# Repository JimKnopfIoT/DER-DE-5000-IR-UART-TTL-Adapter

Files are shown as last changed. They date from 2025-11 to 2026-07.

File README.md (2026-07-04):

# DER EE DE-5000 IR-UART TTL-Adapter
3D printable IR-UART TTL-Adapter to connect a DER EE DE-5000 LCR Meter to a PC. Created with Rhino 8.

I stumbled across a thread on the eevblog forum about a piece of software to connect the DER EE DE-5000 using a self-made infrared-to-UART TTL bridge.
There was a 3D-printable enclosure. Since I own a DER EE DE-5000 LCR Meter, I redesigned the enclosure a bit to fit the contour of the device.

The enclosure consists of two parts that clamp together. When inserting the adapter, press a bit harder until it snaps.
Inside is a CP2102 UART adapter, an L-53P3C IR phototransistor (long leg connected to GND, short leg connected to RX) and a 4.7k Ohm resistor.
The resistor can have any value between 1k and 10k. I chose the 4.7k one because I have plenty of them.
I used some Kapton tape under the resistor.

The software can be found on the internet. It should also work with TestController (a well-known Java app).
I use 19200 baud 8N1, and on Windows I disabled power saving for this device in the Device Manager.

For printing the enclosure I used PETG and a 0.25 mm nozzle on my Prusa MK4S at 0.12 mm layer height.

<p align="center">
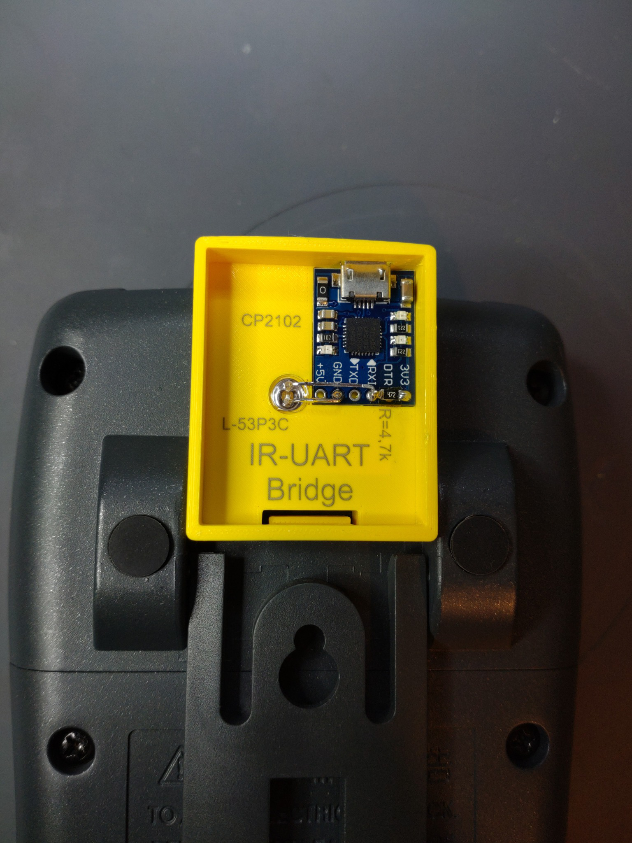
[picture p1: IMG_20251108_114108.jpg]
 
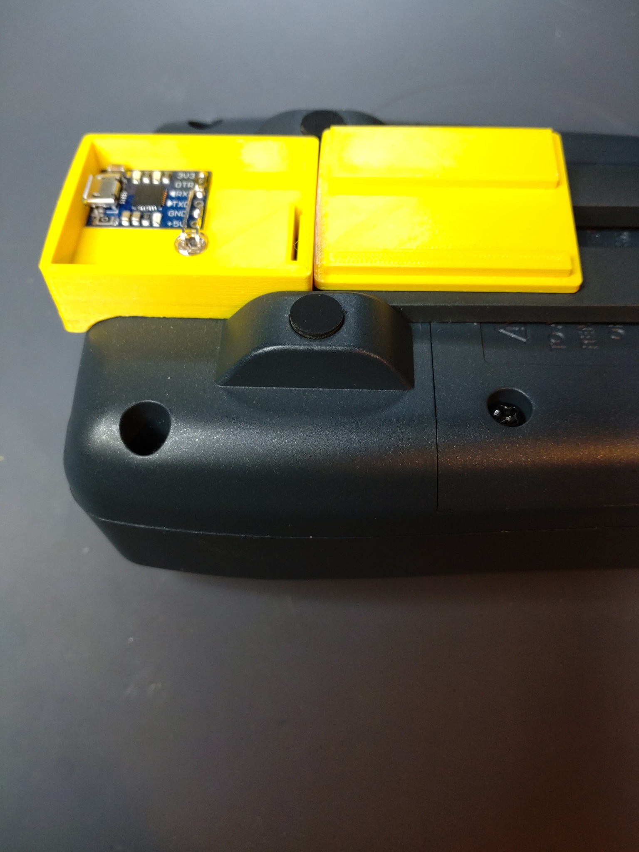
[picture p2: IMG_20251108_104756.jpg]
 
</p>

<p align="center">
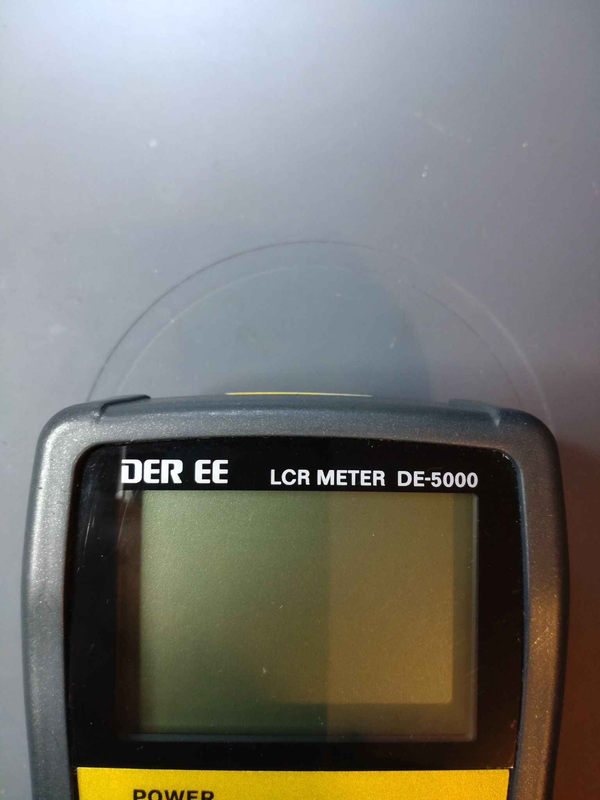
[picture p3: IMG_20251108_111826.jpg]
 
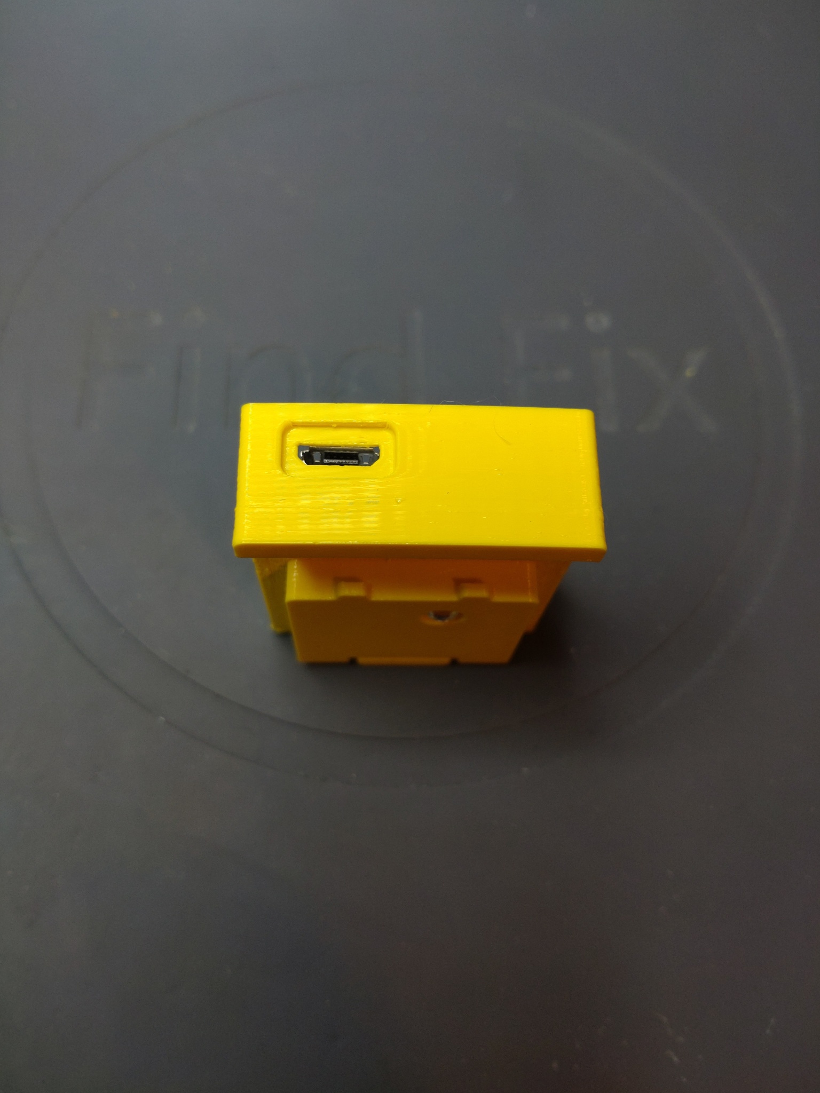
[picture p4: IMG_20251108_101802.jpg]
 
</p>

<p align="center">
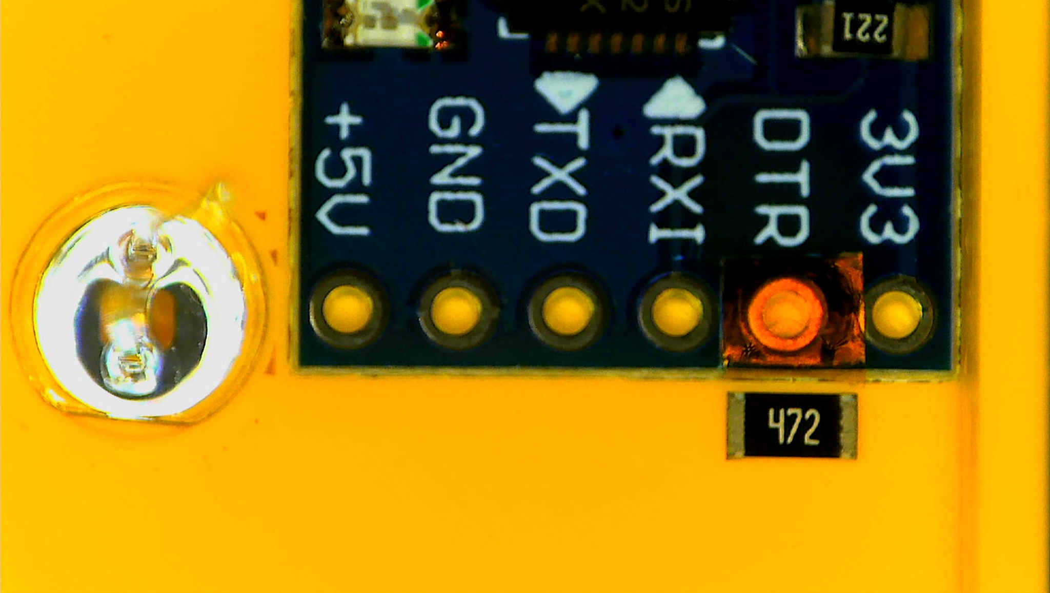
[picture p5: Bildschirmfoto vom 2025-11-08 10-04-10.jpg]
 
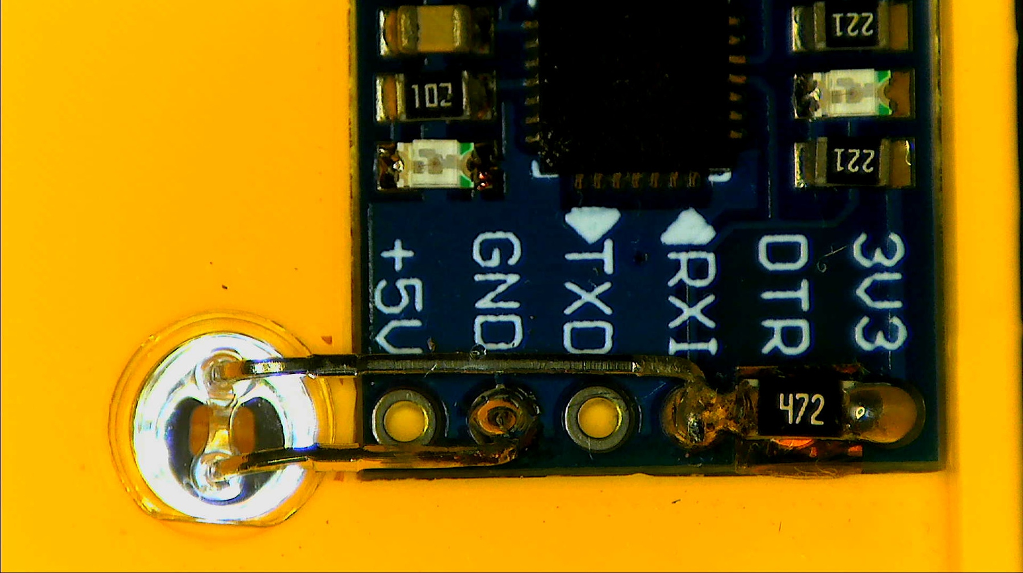
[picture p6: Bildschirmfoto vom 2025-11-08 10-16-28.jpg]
 
</p>

<p align="center">
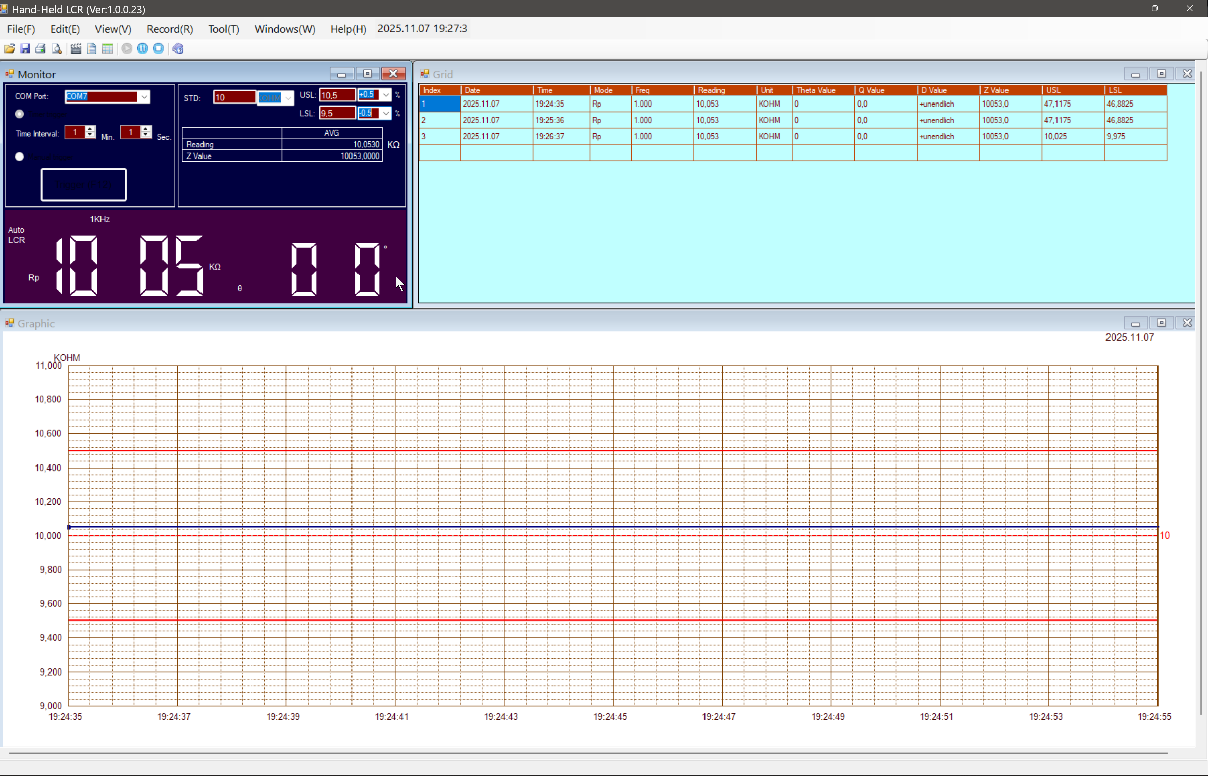
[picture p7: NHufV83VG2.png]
 
</p>

---

## **RN4871 Version (Bluetooth Low Energy)**

After the wired CP2102 version I built a wireless variant based on a Microchip **RN4871** BLE module. Instead of a USB cable, the meter data is now sent over Bluetooth Low Energy, so the meter stays completely galvanically isolated and cable-free from the PC.

<table align="center" border="0" cellspacing="8" cellpadding="0">
  <tr>
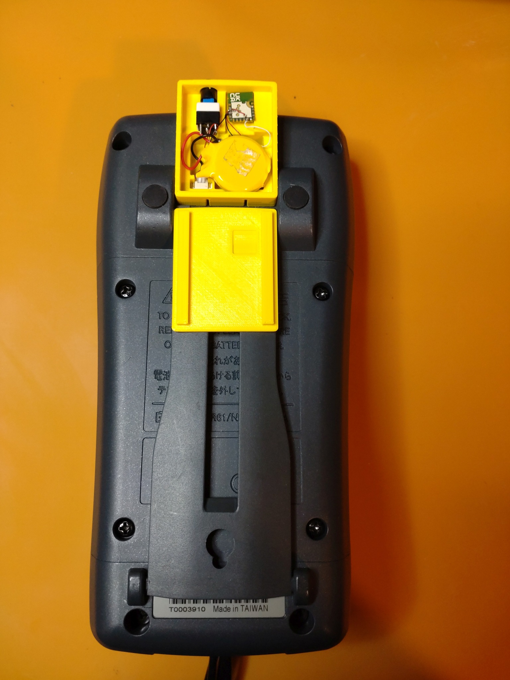
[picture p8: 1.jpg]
    <td></td>
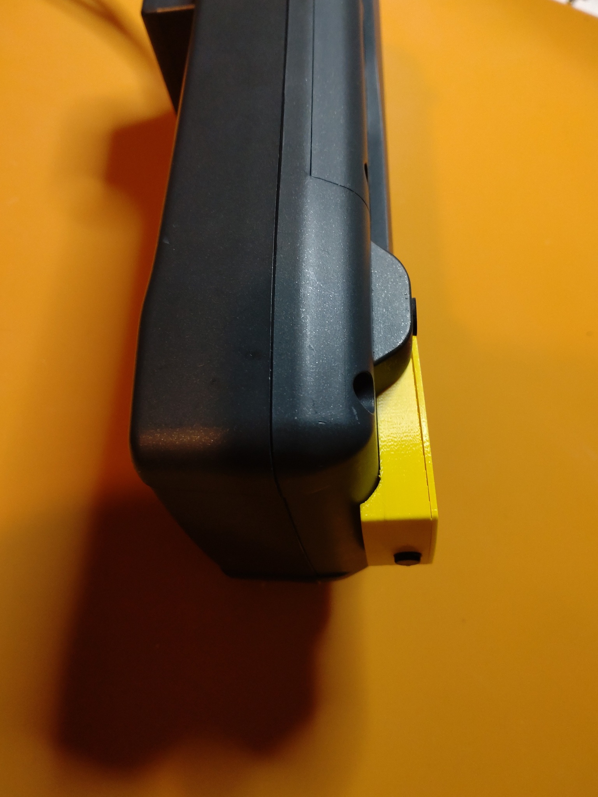
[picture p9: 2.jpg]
    <td></td>
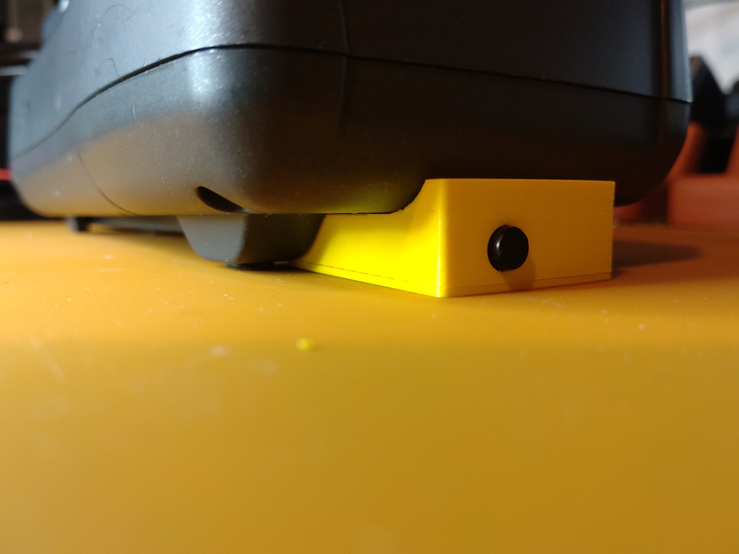
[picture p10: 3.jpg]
    <td></td>
  </tr>
  <tr>
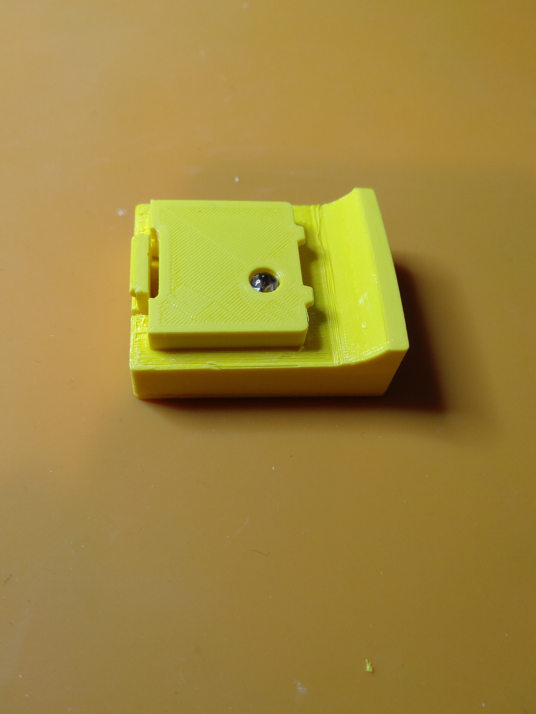
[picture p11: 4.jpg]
    <td></td>
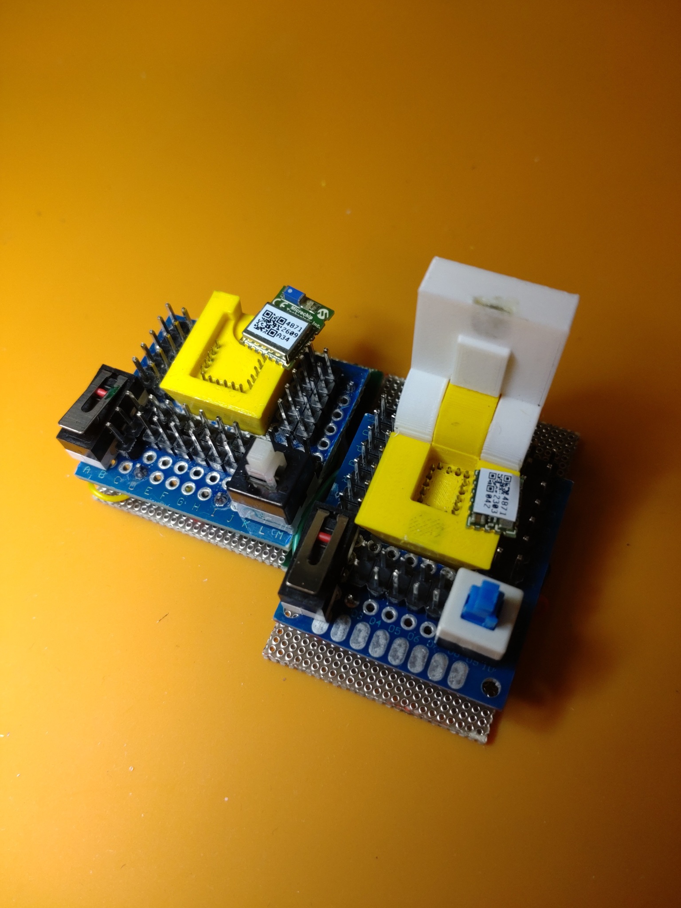
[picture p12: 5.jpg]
    <td></td>
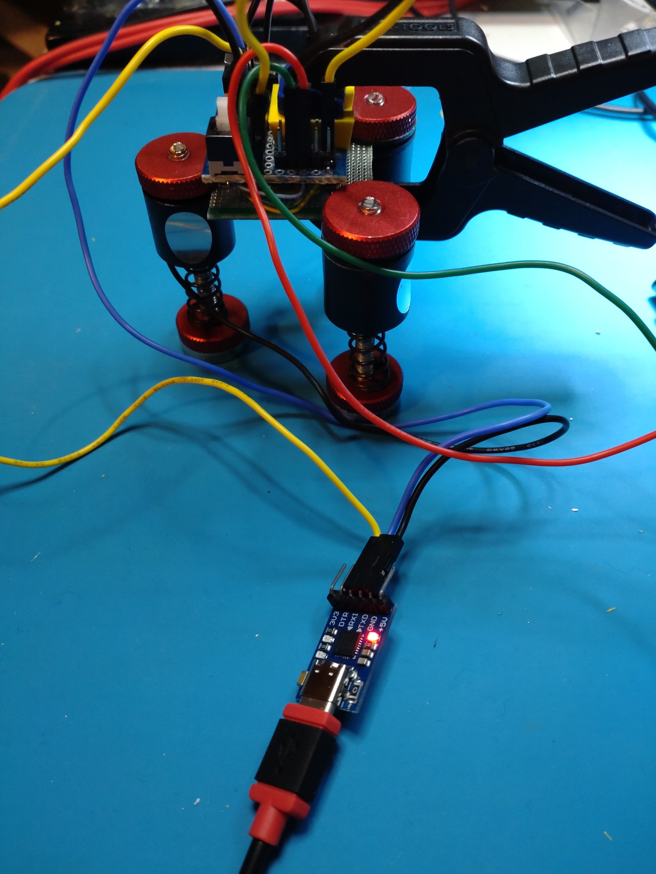
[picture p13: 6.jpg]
    <td></td>
  </tr>
  <tr>
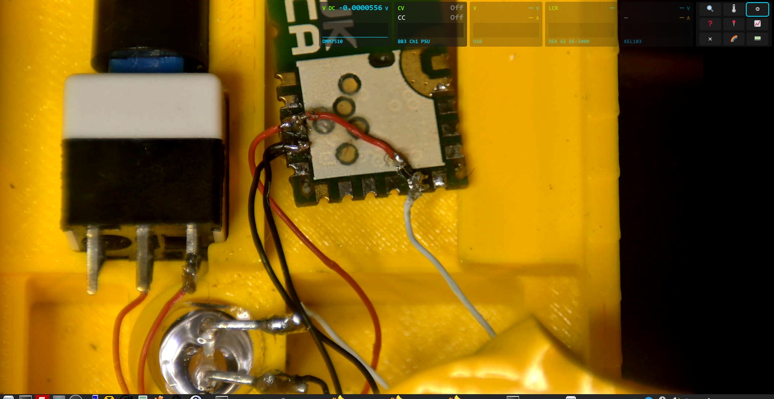
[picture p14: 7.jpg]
    <td></td>
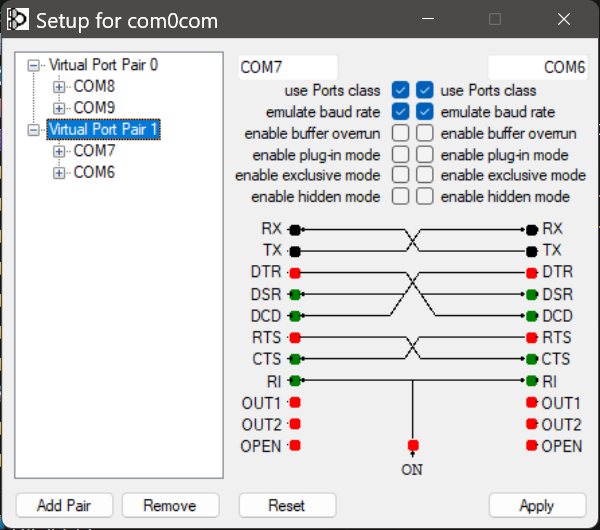
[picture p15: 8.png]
    <td></td>
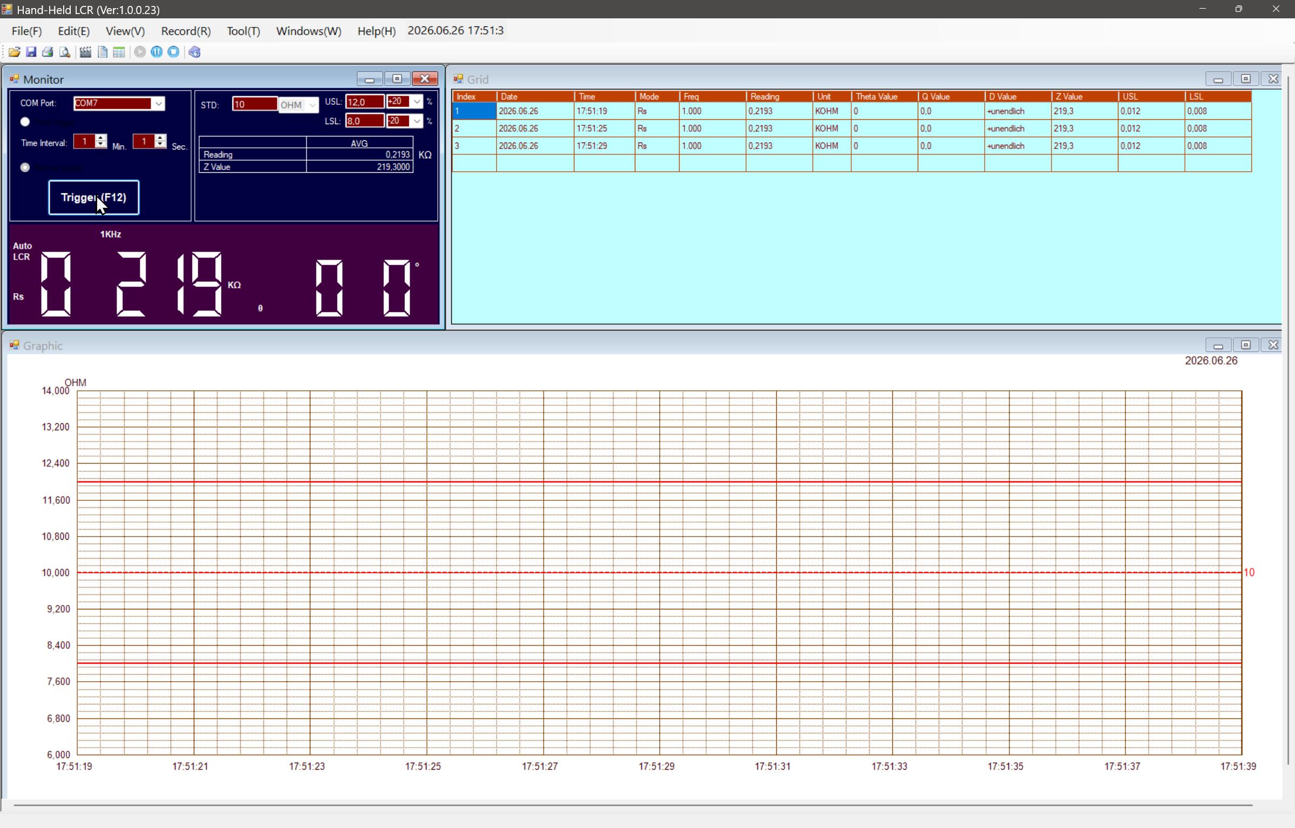
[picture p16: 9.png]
    <td></td>
  </tr>
  <tr>
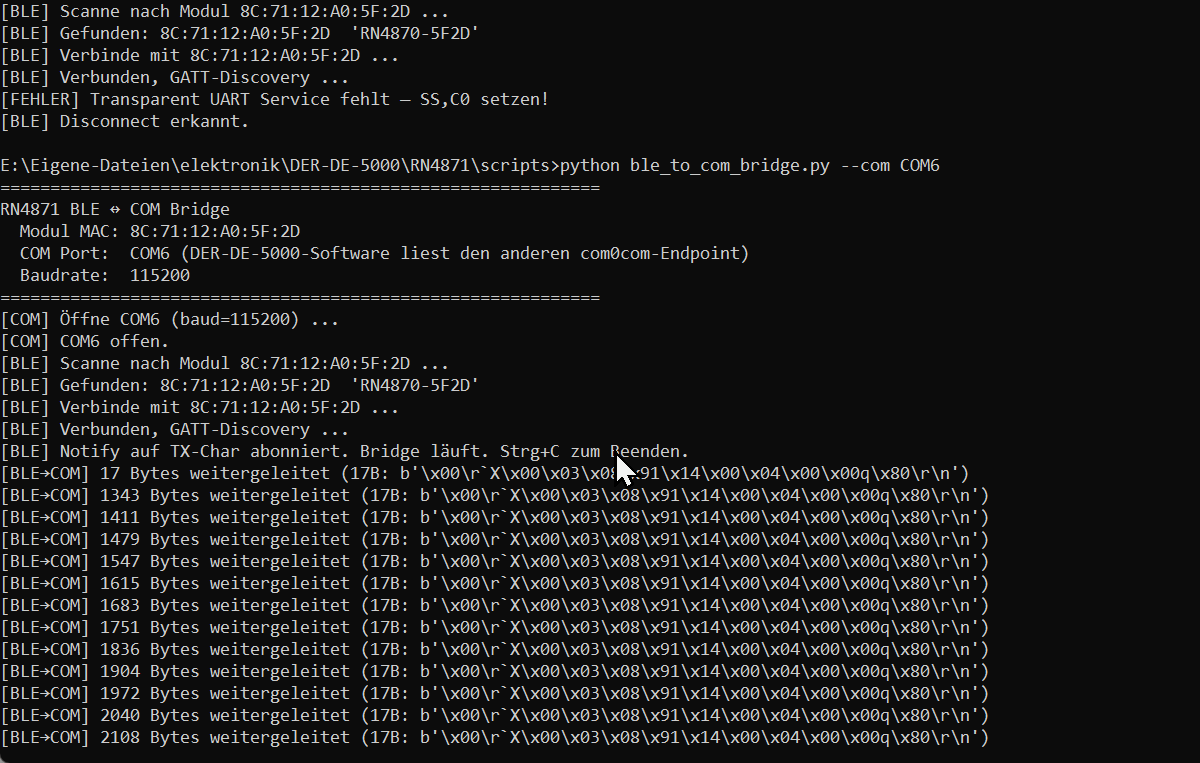
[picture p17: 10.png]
    <td></td>
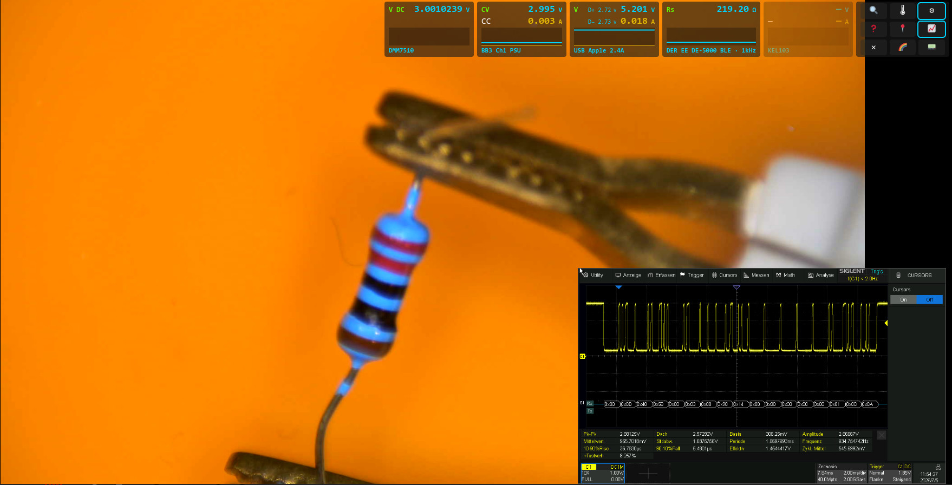
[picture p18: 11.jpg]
    <td></td>
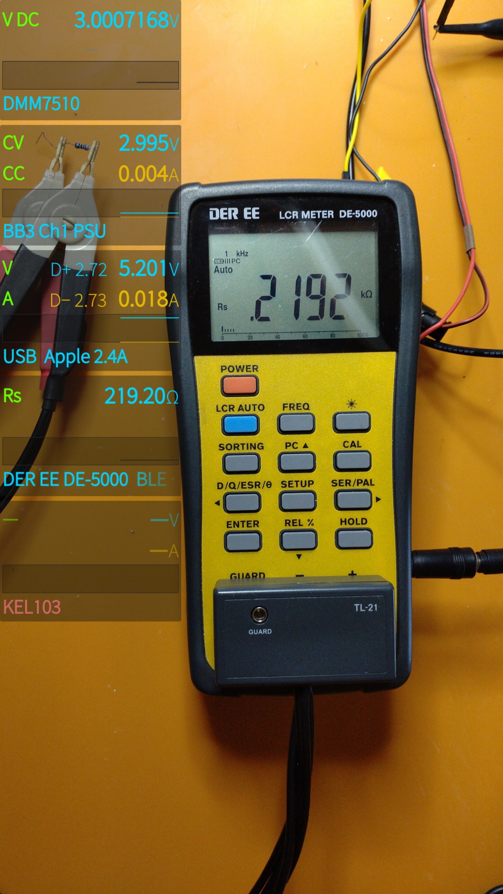
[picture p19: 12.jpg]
    <td></td>
  </tr>
</table>

### How it works

The optical front-end uses the same idea as the USB version, but tuned for the RN4871's UART input. The L-53P3C IR phototransistor sits between the RN4871 **RX** pin and **GND**, and a single **680 Ohm** pull-up resistor connects that same RX node to **3.3 V**. When the meter's IR LED sends a data pulse, the phototransistor conducts and pulls the RX line low; between pulses the pull-up brings it back high. That RX node is wired **directly** to the RN4871 RX pin — on the RX side no Schmitt trigger, no inverter and no capacitor are needed.

> ⚠️ **Decoupling capacitors are mandatory (VDD ↔ GND).** The RN4871 needs two bypass capacitors between **VDD (pin 12)** and **GND (pin 11)**: a **100 nF** ceramic (X7R/X5R) right at the pin for high-frequency filtering, plus a larger **4.7 µF – 10 µF** low-ESR capacitor in parallel as an energy reservoir. Keep both as short as possible (< 5 mm) and star the ground to the module's GND pin.

Do not skip these — this cost us a lot of debugging. On start-up and especially during BLE pairing the radio draws very short microsecond current spikes far above the average (well over 50 mA), which a bench supply's slow averaging never even shows. Without a local reservoir those spikes collapse the voltage at the VDD pin, the module browns out and drops into a reboot/crash loop: it never finishes booting, can't be programmed or paired reliably, and Windows pairing fails every time in a way that looks exactly like a firmware bug. Adding the two capacitors was what finally made the whole chain stable.

Getting there took a few detours. An inverting Schmitt trigger turned out to be a polarity dead-end (it mostly reacted to ambient light instead of the meter). The RN4871 also has a surprisingly high UART input threshold (roughly 70 % of VCC), so the pull-up value matters: 470 Ohm keeps the phototransistor too close to saturation, 1k is already too slow, and **680 Ohm is the sweet spot** for clean edges at 9600 baud 8N1.

The DE-5000 sends its IR data at **9600 baud 8N1**, but the RN4871's UART defaults to 115200 baud out of the box. So the module has to be reconfigured once to 9600 baud (command mode: `SB,09`, then reboot) so that its transparent UART matches the meter — otherwise the incoming serial stream is garbled.

The RN4871 runs in transparent UART mode and forwards the raw serial stream over BLE. On the PC side the data flows like this:

**RN4871 (BLE) → BLE-to-COM bridge (Windows) → com0com virtual COM pair → DER EE PC software**

Since I'm not a software developer, I let Claude code a BLE-to-COM-port bridge for the Windows side. It connects to the RN4871, receives the BLE notifications and feeds them into a com0com virtual serial port pair, so the original DER EE PC software just sees a normal COM port and displays the measured value (for example 219.0 Ω) exactly as it would over the cable.

The matching enclosure for this version is included as `DE-5000_IR_RN4871_housing.stp`, `DE-5000_IR_RN4871_housing.stl`, `DE-5000_IR_RN4871_housing-cover.stp`, `DE-5000_IR_RN4871_housing-cover.stl` and also in the `DE-5000_IR_RN4871.3dm`.

---

## **Programming Adapter (Pogo-Pin Fixture)**

Getting the firmware onto the module and setting its baud rate turned out to be one of the trickiest parts of the whole build. I made several attempts to program the **RN4871** (and the even smaller **RN4871U**), but because the module is so tiny and its pads sit so close together, the usual approach of soldering it to a piece of standard perfboard simply did not work — the pad pitch is finer than a 2.54 mm hole grid and the pads are almost impossible to reach reliably by hand.

<table align="center" border="0" cellspacing="8" cellpadding="0">
  <tr>
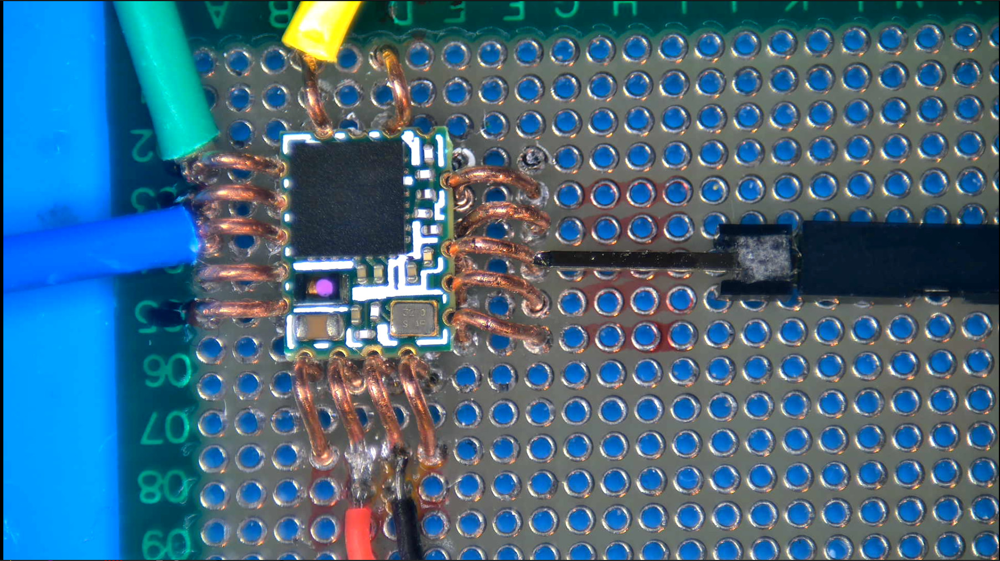
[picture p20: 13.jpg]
    <td></td>
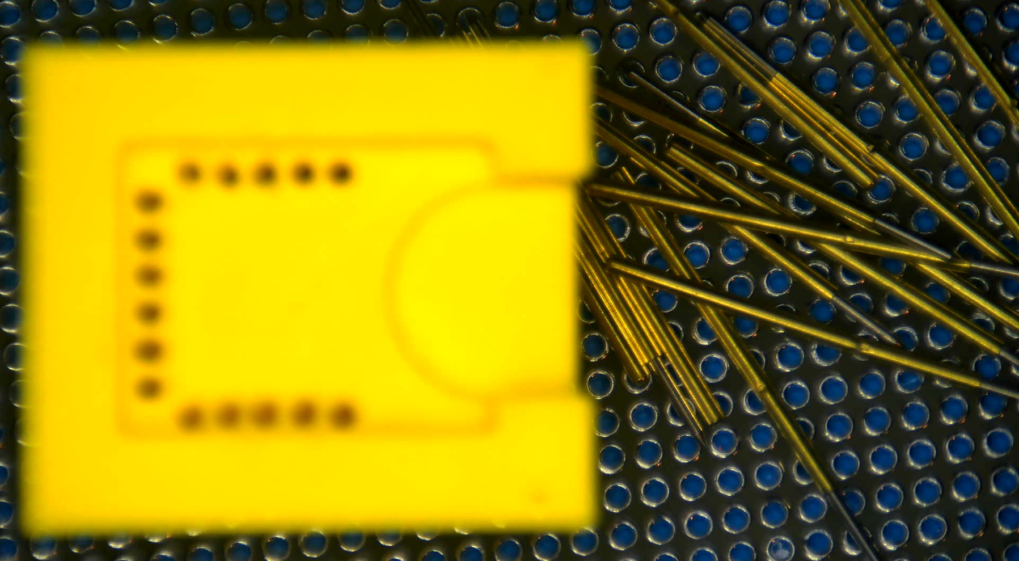
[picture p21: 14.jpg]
    <td></td>
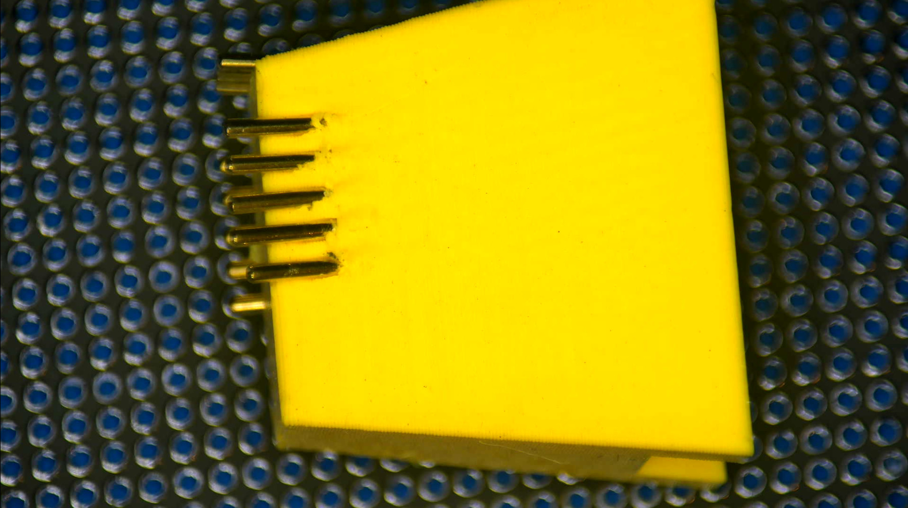
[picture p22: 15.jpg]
    <td></td>
  </tr>
  <tr>
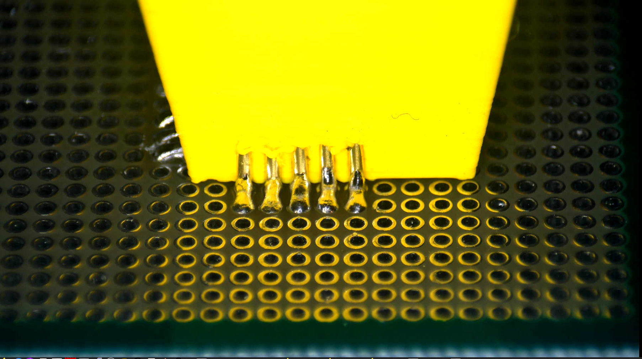
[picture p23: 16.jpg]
    <td></td>
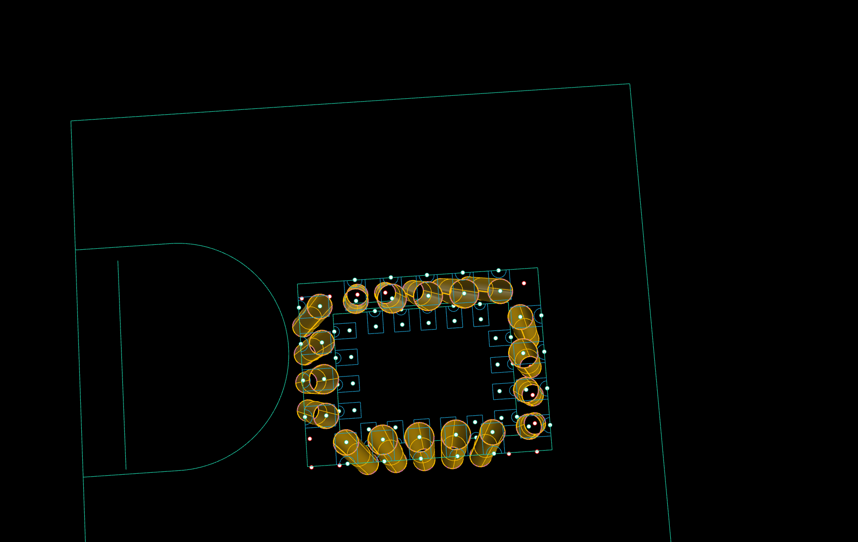
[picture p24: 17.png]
    <td></td>
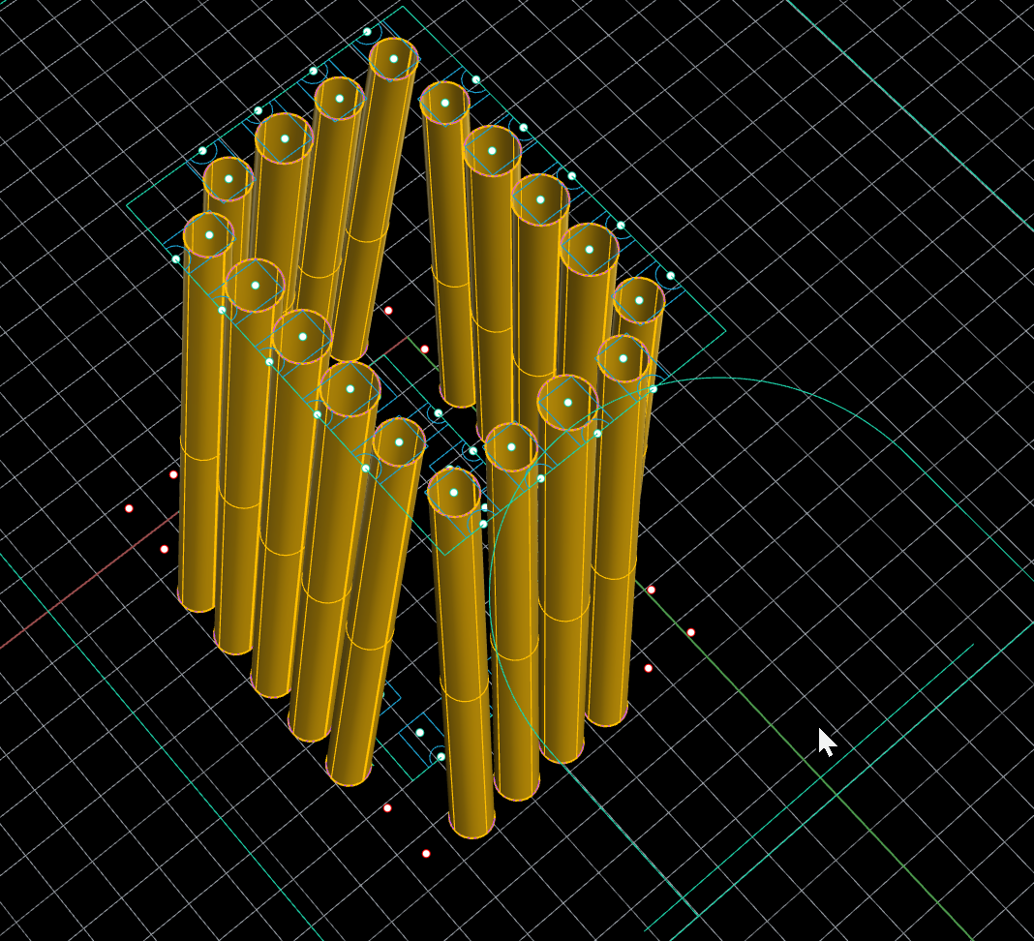
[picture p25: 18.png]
    <td></td>
  </tr>
  <tr>
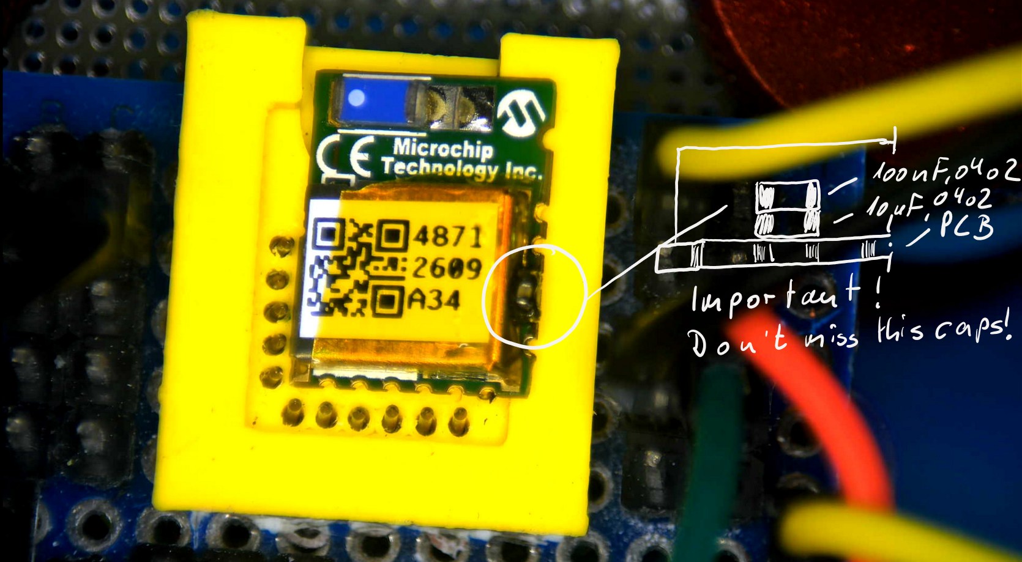
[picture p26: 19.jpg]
    <td></td>
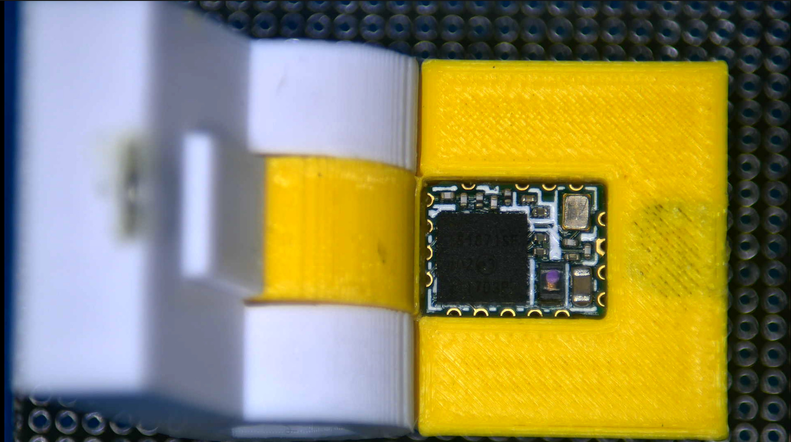
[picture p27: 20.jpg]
    <td></td>
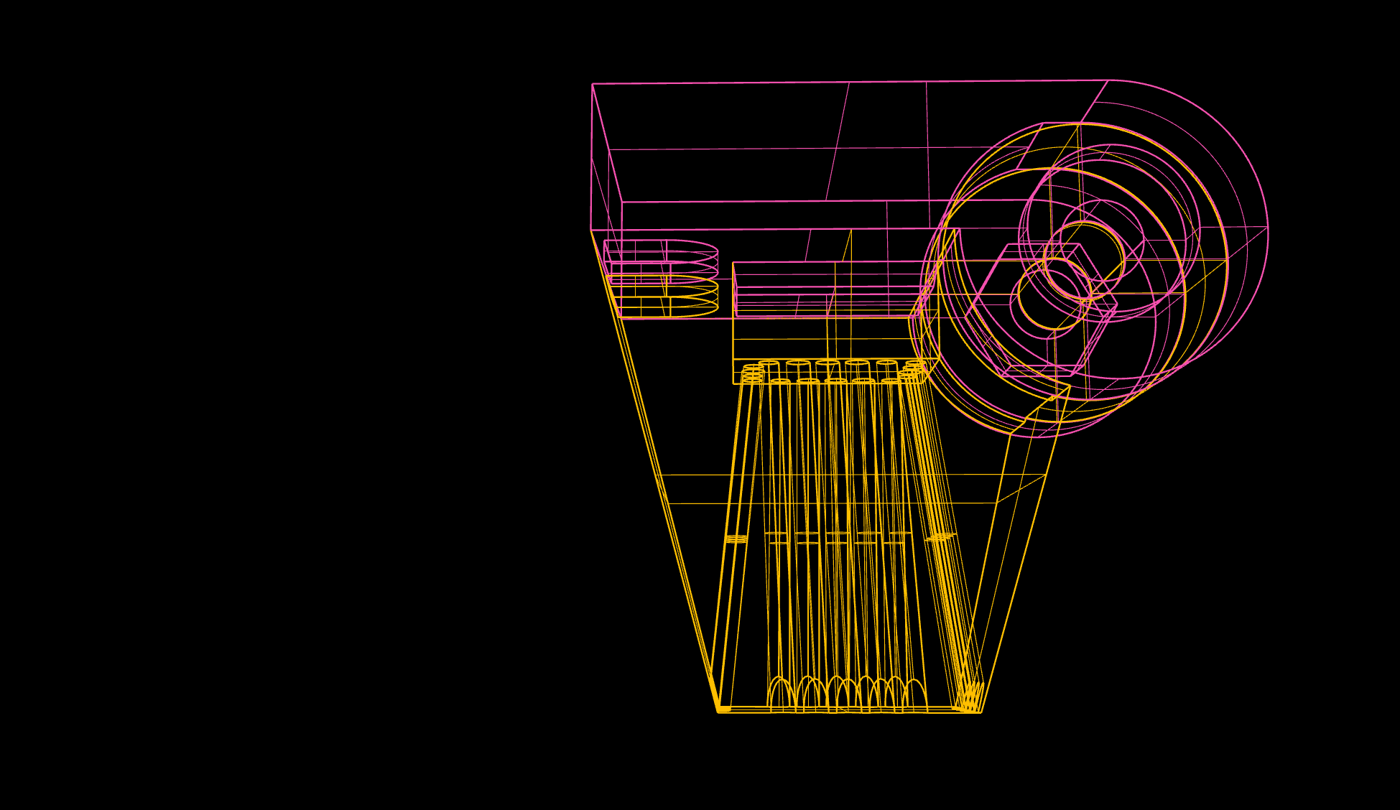
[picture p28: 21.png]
    <td></td>
  </tr>
  <tr>
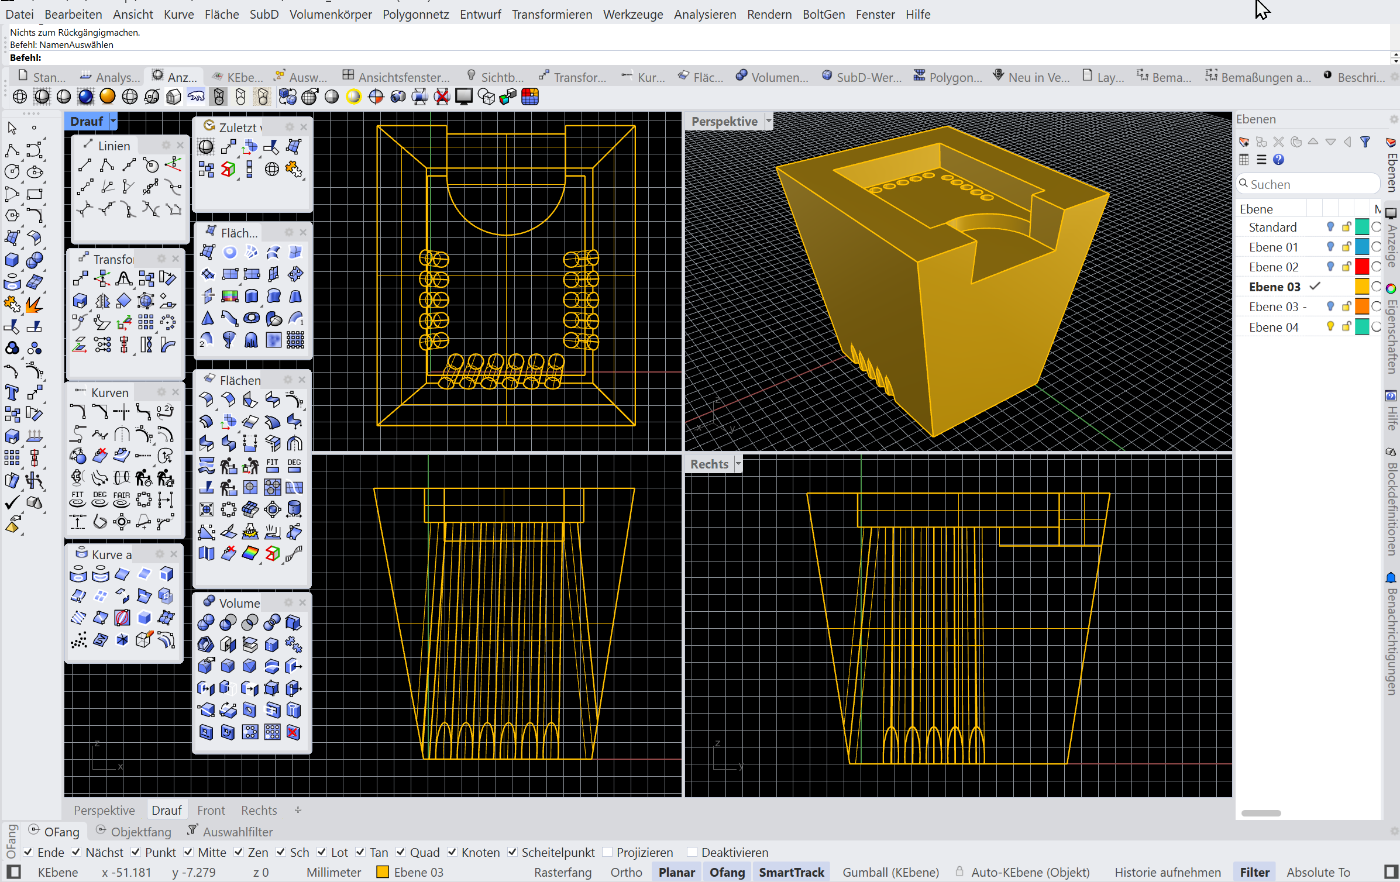
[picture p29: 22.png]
    <td></td>
    <td></td>
    <td></td>
  </tr>
</table>

### How it works

So I designed a dedicated programming adapter that holds the module and contacts its pads with **pogo-pins**. The pins are mounted at a slight angle: at the **top** they land exactly on the module's pads, while at the **bottom** they line up with a standard **2 mm PCB grid**. The pogo-pins are soldered to that PCB on the underside, which also mechanically holds the whole adapter together and keeps everything rigid while the module is dropped in. On the RN4871 version the module is kept in position by a small **plastic clamp**.

Two of the module's control lines have to be toggled while flashing: **RESET_N** (active low) and **P2_0** (pin 4 — low = bootloader / programming mode, high or open = normal application). Both got a switch/button on the adapter, so the module can be put into programming mode and reset without any re-wiring.

> ⚠️ The same two decoupling capacitors from the finished build are essential here as well: a **100 nF** and a **10 µF** (0402) between VDD and GND — see image 19. Without them the module browns out during flashing and programming simply fails.

There are two versions of the fixture, one for the **RN4871** and one for the **RN4871U**. The RN4871U version is a bit more advanced: instead of the plastic clamp it has a **lid that is held closed by two mini neodymium magnets**. The files are `RN4871_fixture.stp`, `RN4871_fixture.stl` and `RN4871U_fixture.stp`, `RN4871U_fixture.stl` (plus the lid, `RN4871U_fixture_lid.stl` / `RN4871U_fixture_Lid.stp`), and the editable Rhino sources `RN4871_fixture.3dm` / `RN4871U_fixture.3dm`.

---

## **Software — BLE-to-COM Bridge & Tools**

The RN4871 exposes Microchip's **Transparent UART** service over Bluetooth Low Energy, but Windows does not turn that into a serial port by itself — so the meter's original PC software cannot see it. All the software needed to close that gap lives in [`software/`](software/): a bridge that pipes the BLE data into a virtual COM port, plus the collection of small Python tools I used to flash, configure and debug the module along the way.

Everything is Python 3.8+ and depends only on `bleak` (BLE) and `pyserial`:

```
pip install bleak pyserial
```

> **Note:** all MAC addresses and network hosts in these scripts are placeholders (`AA:BB:CC:DD:EE:FF`, `192.0.2.10`). Pass your own module MAC with `--mac`, and the lab-supply host (only used by the debug tools) via the `BB3_HOST` environment variable. The Microchip RN4870/71 firmware is proprietary and is **not** included — the flashing scripts expect you to supply your own hex file.

### How I got here (the parts that cost time)

This did not work on the first try. The path, roughly in order:

1. **Optical polarity.** The first attempt fed the IR signal through an inverting Schmitt trigger. That was a dead end — it mostly reacted to ambient light and inverted the polarity the wrong way. Dropping it and wiring the phototransistor with a plain 680 Ω pull-up straight into RX (see the hardware section above) was what actually worked.
2. **The pairing crash-loop.** Modules would connect for 2–4 seconds and then reboot roughly every 4 s. It looked exactly like a firmware bug, and I mis-configured several modules chasing it. The real cause (confirmed via the Microchip forum) was **missing VDD decoupling capacitors**: the BLE radio's microsecond current spikes browned out the supply. Adding the 100 nF + 4.7–10 µF caps fixed pairing instantly. This is why those caps are called out as mandatory above.
3. **Peer address type matters.** The RN4870/71 has a known quirk where "public address" central devices (Windows, most Android) pair far less reliably than "random/RPA" ones (iPhone). Windows still works once the caps are in place, but expect a few connect/disconnect retries.
4. **Baud rate.** The module's UART defaults to 115200, while the DE-5000 sends at 9600 — so the RN4871 has to be reconfigured once (`SB,09`, then reboot). See `set_baud_9600_ble.py` / `set_baud_9600.py`.
5. **Pairing alone is not enough.** Even after a successful pair, Windows drops the idle BLE link — an application has to actively **subscribe to the TX characteristic notifications** to keep data flowing. That is exactly what the bridge does.
6. **No automatic COM port.** Windows never creates a serial port for a BLE Transparent-UART device. The fix is a **com0com** virtual COM pair plus the Python bridge that copies every BLE notification into it, so the meter software just sees a normal COM port.

### The BLE side — Transparent UART subscription

The data path on the module is Microchip's Transparent UART (also called the ISSC/Transparent service). It uses three fixed UUIDs, which is the part that is easy to miss when writing your own client:

| Role | UUID | Properties |
|---|---|---|
| **Service** (Transparent UART) | `49535343-FE7D-4AE5-8FA9-9FAFD205E455` | — |
| **TX characteristic** (module → PC) | `49535343-1E4D-4BD9-BA61-23C647249616` | **Notify** (+ Write) |
| **RX characteristic** (PC → module) | `49535343-8841-43F4-A8D4-ECBE34729BB3` | Write / Write-without-response |

To receive the meter data you connect, then call `start_notify()` on the **TX characteristic** — each measurement packet then arrives as a GATT notification. The RX characteristic is only needed if you want to send data *to* the module; for this one-way meter link it stays unused. The Transparent UART service must be enabled on the module (`SS,C0`); if `bleak`'s service discovery does not list the service UUID above, enable it first (see `configure_tx_uart.py`).

### Windows setup, step by step

1. **Module powered and advertising** — 3.3 V on VDD/GND, the two decoupling caps in place, reconfigured to 9600 baud. A Reset press should make it advertise; a generic BLE scanner (e.g. *Bluetooth LE Explorer*) confirms it is visible.
2. **Install com0com** (use the signed build — newer Windows rejects the unsigned driver) from <https://com0com.sourceforge.net/>. Let the installer create the default `CNCA0 ↔ CNCB0` pair.
3. **Name the pair** to two COM numbers, e.g. `COM10 ↔ COM11`, either in the com0com setup GUI or from an Admin prompt:
   ```cmd
   cd "C:\Program Files (x86)\com0com"
   setupc.exe change CNCA0 PortName=COM10
   setupc.exe change CNCB0 PortName=COM11
   ```
   `COM10` is the bridge's end, `COM11` is the end the meter software reads.
4. **Install the Python packages:** `pip install bleak pyserial`.
5. **Find your module's MAC** with a BLE scanner, then **start the bridge**:
   ```cmd
   python software\scripts\ble_to_com_bridge.py --mac AA:BB:CC:DD:EE:FF --com COM10 --baud 9600
   ```
   It scans, connects, subscribes to the TX notifications and forwards them to `COM10`, reconnecting automatically if the link drops. **Leave this window open** while measuring.
6. **Point the meter software at `COM11`** — 9600 8N1, flow control off. The measured values now appear as if the meter were wired over USB.

Common snags: the bridge `--baud` and the meter-software baud must match; make sure the software uses the *other* com0com port (COM11, not COM10); if the module crash-loops, re-check the decoupling caps and the 3.3 V supply.

### The tools in `software/`

The production path only needs `ble_to_com_bridge.py`; the rest are the flashing, configuration and diagnostic helpers built up during the project. A short quick-reference also lives in [`software/scripts/README.md`](software/scripts/README.md).

**Bridge / receiving**
| Script | What it does |
|---|---|
| `scripts/ble_to_com_bridge.py` | **Main tool.** Connects to the module, subscribes to the TX characteristic and forwards every BLE notification into a com0com COM port; auto-reconnect, optional COM→BLE direction. |
| `scripts/windows_receiver.py` | Console-only receiver — prints the BLE stream without com0com, for a quick "are bytes arriving?" check. |
| `scripts/ble_hex_monitor.py` | Dumps the incoming BLE notifications as raw hex, for protocol inspection. |

**Configuration**
| Script | What it does |
|---|---|
| `scripts/set_baud_9600_ble.py` | Sets the module's UART to 9600 baud remotely over BLE (`SB,09` + reboot). |
| `scripts/set_baud_9600.py` | Same, but over the wired CP2102 UART, and verifies by reconnecting at 9600. |
| `scripts/configure_tx_uart.py` | Enables the Transparent UART service / sets the service bitmap (`SS,C0`). |
| `scripts/cmd_after_reboot.py` | Enters command mode inside the ~15 ms window right after `%REBOOT%` (for stubborn modules). |
| `scripts/silent_cmd.py` | Reaches command mode (`$$$`) on a module that is advertising silently. |

**Firmware flashing**
| Script | What it does |
|---|---|
| `scripts/bootloader_test.py` | HCI ping to confirm the module is in the bootloader (P2_0 low + reset). |
| `scripts/update_slow.py` | Flashes firmware over the HCI bootloader, with inter-chunk delays that keep the CP2102 in sync. |
| `scripts/hfiles_combine.py` | Combines the four `H00–H03` firmware files into a single hex (set `RN4871_HEXDIR`). |

**Diagnostics / testing**
| Script | What it does |
|---|---|
| `scripts/raw_monitor.py` | Raw UART monitor — every byte with a timestamp (hex + ASCII). |
| `scripts/uart_loopback.py` | CP2102 loopback test (bridge TX↔RX) to prove the adapter itself is fine. |
| `scripts/uart_trace.py` | Live UART trace plus parallel bench-supply current logging (host via `BB3_HOST`), for connect/brownout diagnosis. |
| `scripts/bb3_watch.py` | Logs voltage/current from a lab supply over SCPI/TCP (development aid; host via `BB3_HOST`). |
| `scripts/de5000_simulator.py` | Emulates the DE-5000's IR data stream, so the whole chain can be tested without the meter. |
| `rn4871_ble_test.py` | BLE scan + connect + GATT service/characteristic discovery. |

The three `.bat` files in `software/` (`start-bridge.bat`, `set-baud-9600.bat`, `monitor-hex.bat`) are just convenience wrappers that call the scripts above on Windows — open them in a text editor and set your own module MAC / COM port at the top.

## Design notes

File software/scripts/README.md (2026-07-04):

# RN4871 Scripts — Quick Reference

Alle Scripts brauchen Python 3.8+. Voraussetzung:
```bash
pip install pyserial intelhex bleak
```

Für BB3-Steuerung: Netzteil muss auf `192.0.2.10:5025` (SCPI/TCP) erreichbar sein.

## Flash-Workflow

```bash
# 1. P2_0 auf GND legen + Reset drücken
python3 scripts/bootloader_test.py
# Erwartung: "→ HCI-Event erkannt — Bootloader lebt!" + 21 Bytes saubere Antwort

# 2. Flash (H-Files = bevorzugt, Rehex hat Bug)
python3 scripts/update_slow.py /dev/ttyUSB0 \
  ../RN4870-71_Firmware_1.44/Hex_Files/rn4871_hfiles_combined.hex

# 3. P2_0 von GND trennen + Reset drücken
# 4. BB3 Power Cycle (5 s OFF, dann ON)
```

## Diagnose

```bash
# Live UART + BB3-Strom über 60s
python3 scripts/uart_trace.py 60 > trace.log

# Strom-Schwankung beobachten
python3 scripts/bb3_watch.py 1 30   # CH1, 30 Sekunden

# CP2102 selbst testen (TX↔RX am Adapter brücken)
python3 scripts/uart_loopback.py

# Raw UART monitor (zeigt jeden Byte)
python3 scripts/raw_monitor.py
```

## Konfigurations-Versuche

```bash
# CMD-Mode im 15ms-Fenster nach %REBOOT% — für SS,/SA,/etc.
python3 scripts/cmd_after_reboot.py

# Wenn Modul silent advertised: $$$ mit normalem Guard
python3 scripts/silent_cmd.py
```

## BLE-Tests

```bash
# Aus Hauptverzeichnis
python3 ../rn4871_ble_test.py --scan        # alle Geräte
python3 ../rn4871_ble_test.py AA:BB:CC:DD:EE:FF   # connect + GATT discovery

# Windows-Empfänger (auf Windows-PC laufen lassen)
python scripts/windows_receiver.py
```

## H-Files kombinieren (falls combined.hex nicht da)

```bash
python3 scripts/hfiles_combine.py
# Erzeugt: RN4870-71_Firmware_1.44/Hex_Files/rn4871_hfiles_combined.hex
```

## Sicherheits-Regeln

1. **BB3 CH1 Limit anfangs 30 mA** bei neuem Modul (VDD/GND-Vertauschung sichtbar als Brownout)
2. Wenn OK: Limit auf **100 mA** (BLE-Peaks brauchen mehr als 30 mA)
3. **3.3 V Pflicht**, nicht 3.0 V
4. **Serial port immer** mit `dsrdtr=False, rtscts=False`

## Bekannte Stolperfallen

| Symptom | Ursache | Workaround |
|---|---|---|
| Strom konstant 4 mA, kein Adv | Stuck mode | Hardware-Reset drücken |
| Flash-Sync-Errors | Stromversorgung wackelt oder 3.0 V | 3.3 V + festes Kabel |
| 100 mA bei 1.4 V | VDD/GND vertauscht | Sofort OFF, Verkabelung prüfen |
| Connect-Timeout aus bleak | Modul advertised gerade nicht | Power-Cycle + 10s-Window |
| Phone findet's nicht | TX-Power zu niedrig | `SGA,0` setzen (riskant) oder näher dran |
| Crash-Loop alle ~4s | Pair-Bug in V1.44 H-Files | Bisher keine Lösung |

Vollständige Dokumentation und der Weg dorthin: siehe die **Software**-Sektion in der Haupt-[README](../../README.md) des Repos.

> Hinweis: MAC-Adressen und Netzwerk-Hosts in diesen Scripts sind Platzhalter
> (`AA:BB:CC:DD:EE:FF`, `192.0.2.10`). Eigene Werte per `--mac` bzw. der
> Umgebungsvariable `BB3_HOST` übergeben. Die Microchip-Firmware (V1.44) ist
> aus Lizenzgründen **nicht** enthalten — für die Flash-Scripts selbst besorgen.

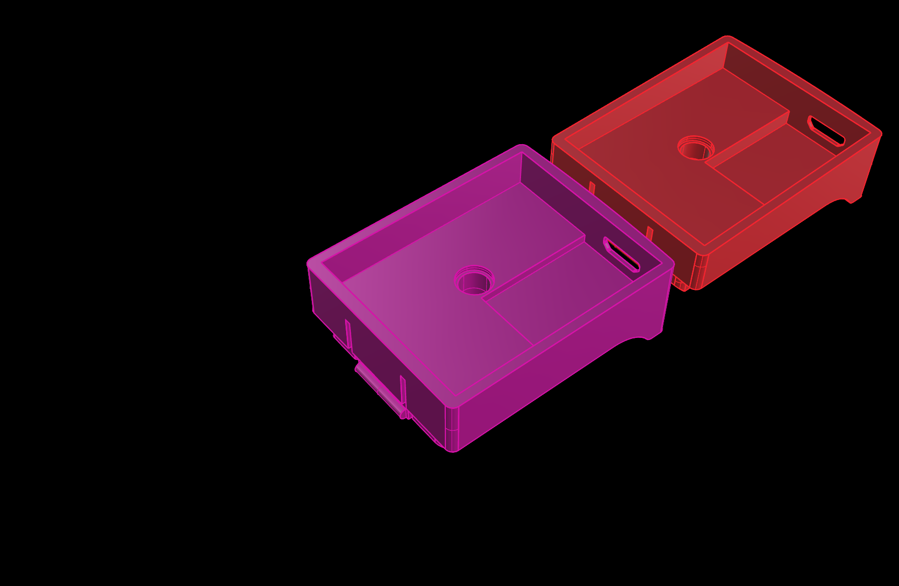
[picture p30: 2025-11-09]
ViewCapture20251109_140748.png

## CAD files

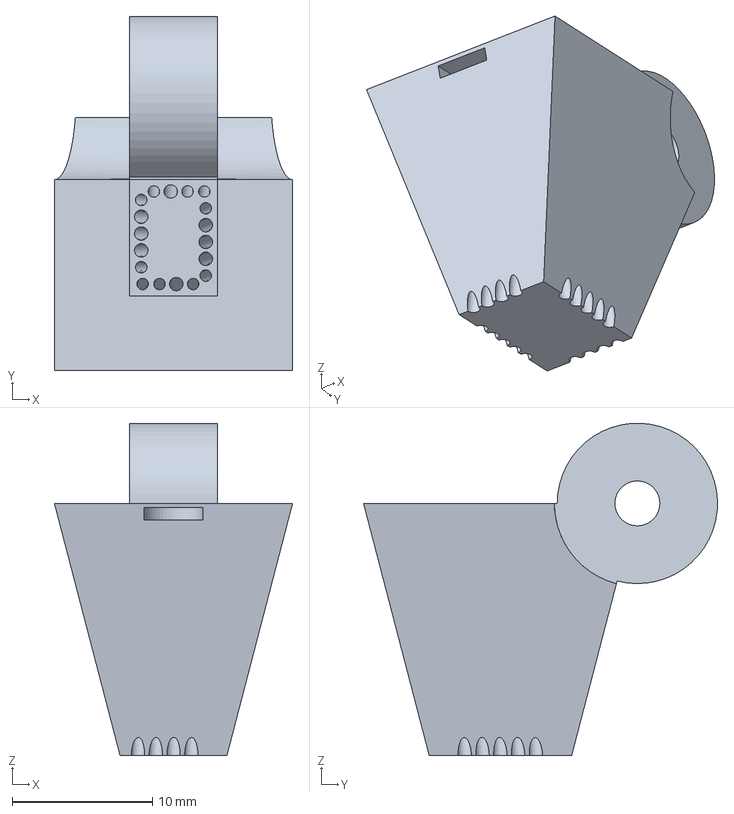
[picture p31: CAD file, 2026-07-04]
RN4871U_fixture.stp
17.0 x 25.3 x 23.7 mm

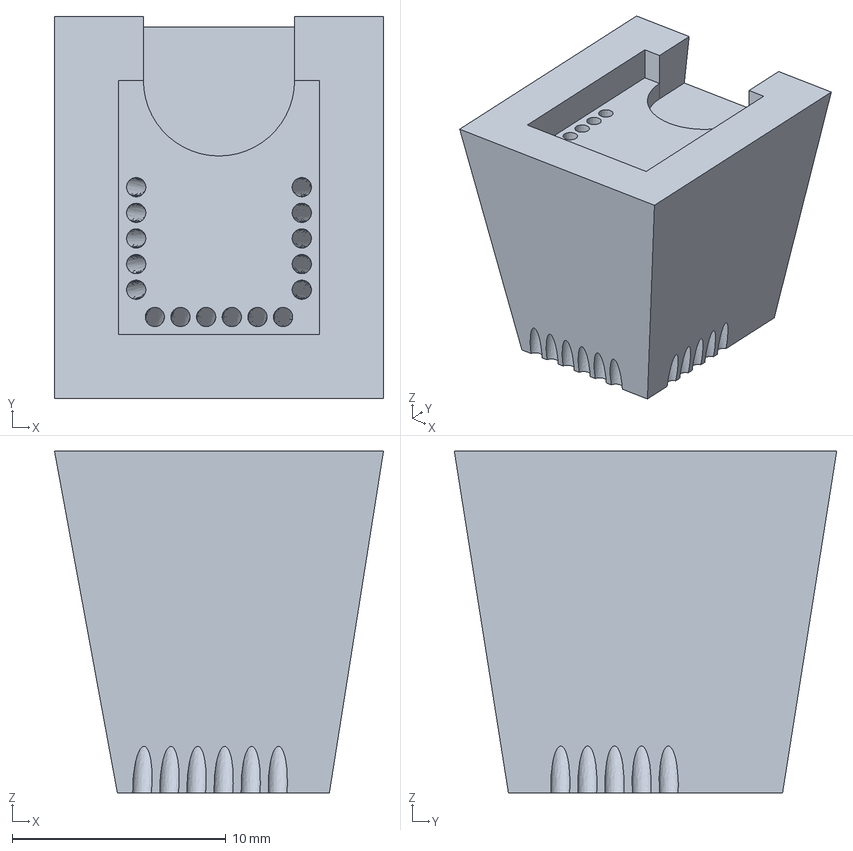
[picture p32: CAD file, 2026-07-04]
RN4871_fixture.stp
15.4 x 17.9 x 16.0 mm

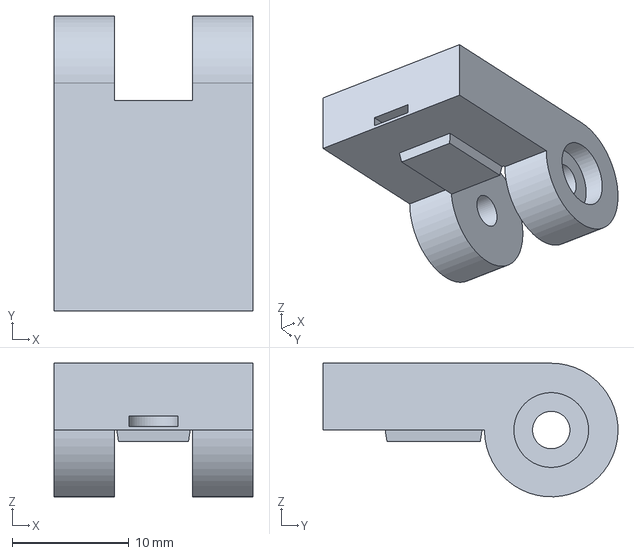
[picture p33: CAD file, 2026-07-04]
RN4871U_fixture_Lid.stp
17.0 x 25.3 x 11.4 mm

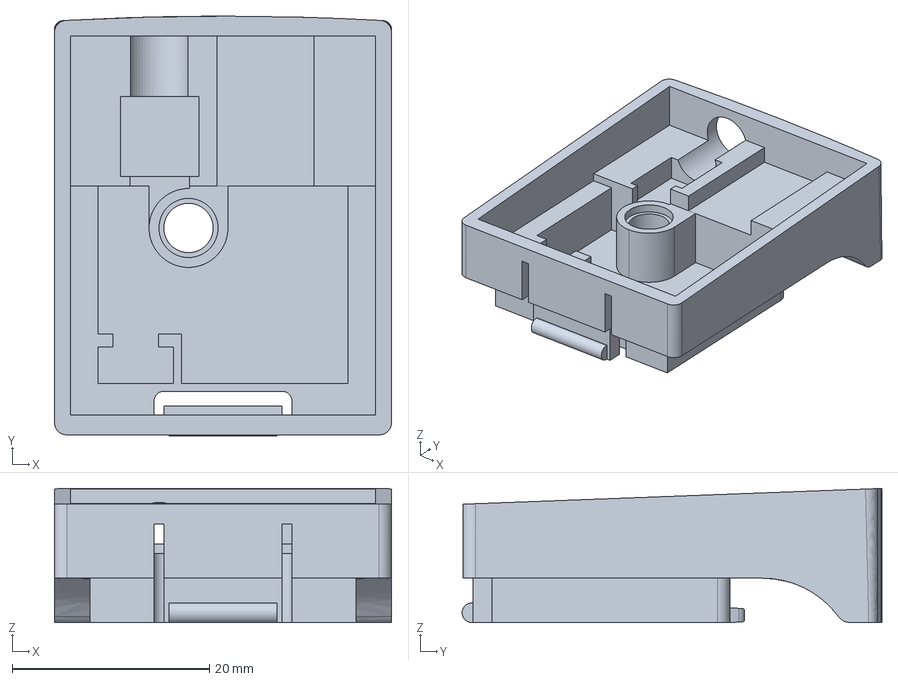
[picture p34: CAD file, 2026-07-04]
DE-5000_IR_RN4871_housing.stp
34.2 x 42.6 x 13.6 mm

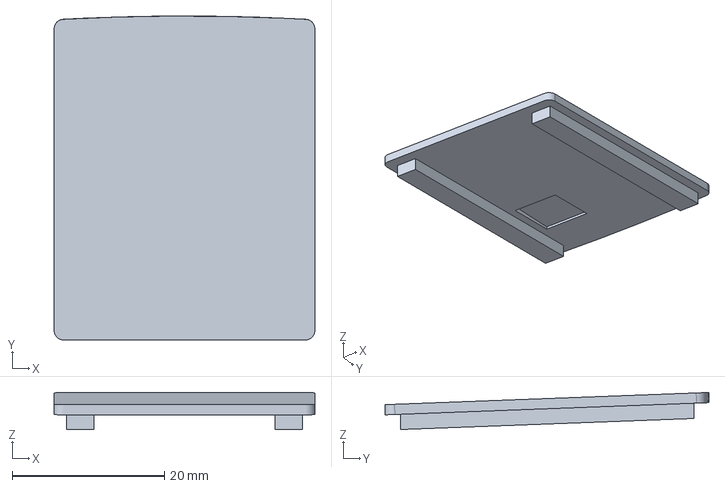
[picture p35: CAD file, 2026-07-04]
DE-5000_IR_RN4871_housing-cover.stp
34.2 x 42.5 x 4.87 mm

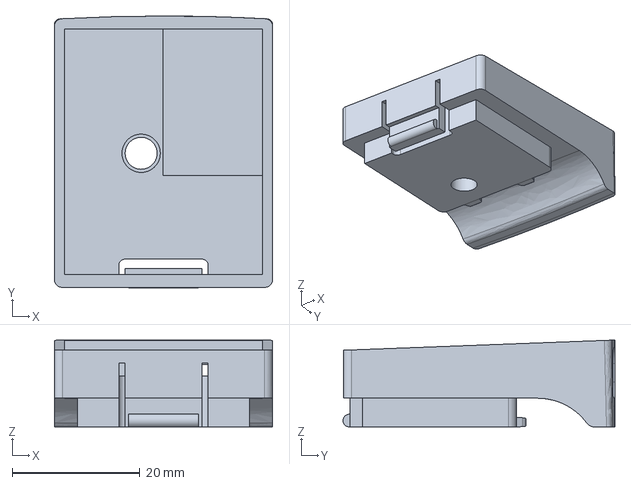
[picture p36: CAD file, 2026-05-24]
Bottom_USB-C_slope.stp
34.2 x 42.6 x 13.6 mm

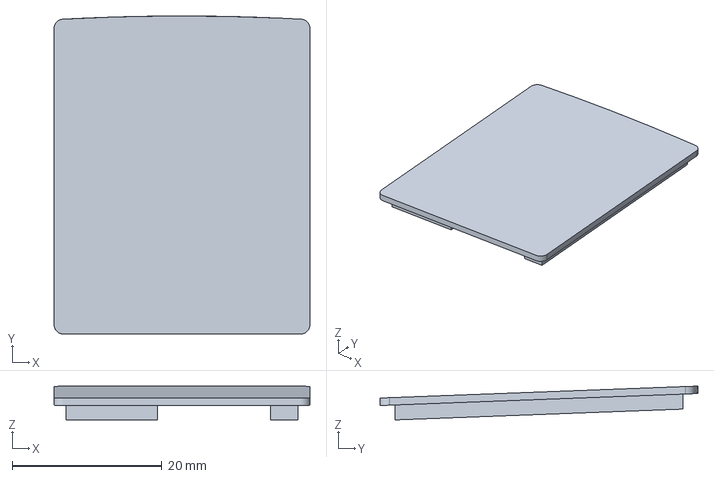
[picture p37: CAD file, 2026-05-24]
Deckel.stp
34.2 x 42.5 x 4.53 mm

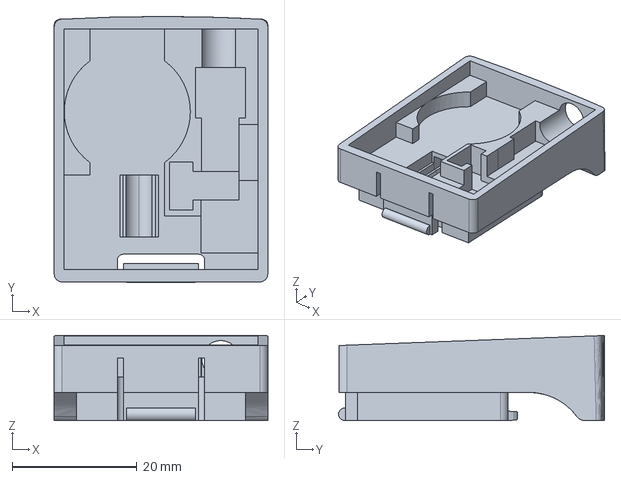
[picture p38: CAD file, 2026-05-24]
Gehäuse.stp
34.2 x 42.6 x 13.6 mm

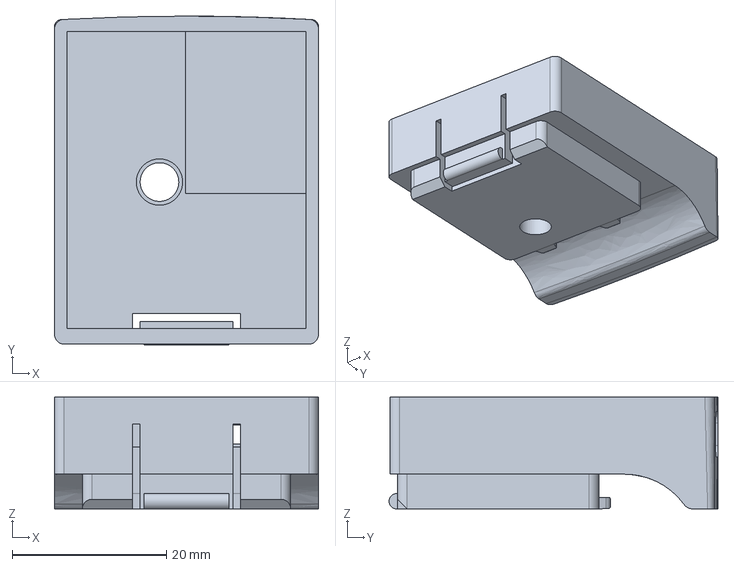
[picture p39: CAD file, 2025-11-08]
Bottom_MicroUSB.stp
34.2 x 42.6 x 14.5 mm

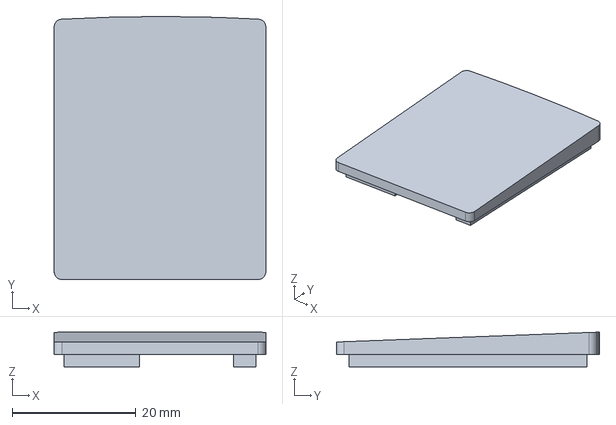
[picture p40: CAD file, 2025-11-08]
Top_slope.stp
34.2 x 42.5 x 5.63 mm

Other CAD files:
Bottom_MicroUSB_slope.stp
Bottom_USB-C.stp
Bottom_MicroUSB.stl
Bottom_MicroUSB_slope.stl
Bottom_USB-C.stl
Bottom_USB-C_slope.stl
DE-5000_IR_RN4871.3dm
DE-5000_IR_RN4871_housing-cover.stl
DE-5000_IR_RN4871_housing.stl
DE-5000_IR_USB.3dm
RN4871U_fixture.3dm
RN4871U_fixture.stl
RN4871U_fixture_lid.stl
RN4871_fixture.3dm
RN4871_fixture.stl
Top_slope.stl

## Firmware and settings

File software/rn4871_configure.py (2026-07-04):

#!/usr/bin/env python3
"""
RN4871 Transparent UART Konfiguration

Strategie (automatisch):
  1. Falls Crash-Loop (wiederholte %REBOOT%): SF,2 im 4s-Fenster senden → stabil
  2. In stabilem Zustand: $$$  → CMD> → SS,C0 → AOK → R,1
  3. Power Cycle danach erforderlich (GATT-Tabelle neu bauen)

Voraussetzung:
  - P2_0 NICHT auf GND (Application Mode)
  - Windows + Linux Bluetooth AUS
  - UART-Adapter an /dev/ttyUSB0

Aufruf:
  python3 rn4871_configure.py [/dev/ttyUSB0]
"""

import serial
import time
import sys

PORT = sys.argv[1] if len(sys.argv) > 1 else '/dev/ttyUSB0'

# Timing-Konstanten (aus User Guide DS50002466C, Abschnitt 1.3 und 2.4.21)
# Guard time: 100ms UART-Stille VOR dem ersten $
GUARD_TIME = 0.15      # 150ms (etwas mehr als das Minimum 100ms)
CMD_WAIT = 0.4         # Wartezeit nach $$$ auf CMD>
CRASH_WINDOW = 0.12    # Delay nach %REBOOT% bevor $$$ gesendet wird


def open_port():
    # dsrdtr=False, rtscts=False: kritisch! Sonst hält DTR das Modul in Reset
    return serial.Serial(PORT, 115200, timeout=0.2, dsrdtr=False, rtscts=False)


def try_enter_cmd(ser):
    """Versucht Command Mode via $$$. Gibt True zurück wenn CMD> empfangen."""
    ser.reset_input_buffer()
    time.sleep(GUARD_TIME)   # 100ms+ Stille VOR $$$
    ser.write(b'$$$')
    time.sleep(CMD_WAIT)
    resp = ser.read(ser.in_waiting or 64)
    print(f"  $$$ -> {resp!r}")
    return b'CMD>' in resp


def send_cmd(ser, cmd, wait=0.4):
    ser.write(cmd if cmd.endswith(b'\r\n') else cmd + b'\r\n')
    time.sleep(wait)
    r = ser.read(ser.in_waiting or 64)
    print(f"  {cmd.decode().strip()} -> {r.decode('ascii','replace').strip()!r}")
    return r


def phase1_stop_crashloop(ser, max_reboots=12):
    """Phase 1: SF,2 im Crash-Loop-Fenster senden um stabilen Zustand zu erreichen."""
    print("\n[Phase 1] Warte auf %REBOOT% (Crash-Loop)...")
    buf = b''
    t0 = time.time()
    reboot_count = 0

    while time.time() - t0 < 60:
        b = ser.read(1)
        if b:
            buf += b
            print(b.decode('ascii', 'replace'), end='', flush=True)
            if len(buf) > 200:
                buf = buf[-100:]

        if b'%REBOOT%' in buf:
            reboot_count += 1
            buf = b''
            print(f"\n  → %REBOOT% #{reboot_count} erkannt, {CRASH_WINDOW*1000:.0f}ms warten...")
            time.sleep(CRASH_WINDOW)
            ser.reset_input_buffer()

            # SF,2 senden (Factory Reset → stoppt Crash-Loop)
            ser.write(b'$$$')
            time.sleep(CMD_WAIT)
            r = ser.read(ser.in_waiting or 64)
            print(f"  $$$ -> {r!r}")

            if b'CMD>' in r:
                print("  CMD> erhalten! Sende SF,2...")
                r2 = send_cmd(ser, b'SF,2', wait=0.3)
                if b'Reboot' in r2 or b'AOK' in r2 or b'REBOOT' in r2.upper():
                    print("  SF,2 OK! Warte auf stabilen Neustart...")
                    # Warte bis Crash-Loop aufhört (~8s)
                    time.sleep(8)
                    return True
                else:
                    print(f"  SF,2 kein Reboot-Token: {r2!r} — warte auf nächsten Versuch")
            else:
                print("  Kein CMD> — nächster Versuch")

        if reboot_count >= max_reboots:
            print(f"  {max_reboots} Reboots ohne SF,2 — Abbruch")
            return False

    print("  Timeout — kein Crash-Loop erkannt")
    return False


def phase2_set_services(ser, max_tries=5):
    """Phase 2: Im stabilen Zustand $$$ senden und SS,C0 setzen."""
    print("\n[Phase 2] Versuche Command Mode für SS,C0...")

    for attempt in range(1, max_tries + 1):
        print(f"  Versuch {attempt}/{max_tries}:")
        if try_enter_cmd(ser):
            print("  CMD> erhalten!")

            # Aktuelle Services lesen
            r = send_cmd(ser, b'GS')
            # SS,C0 setzen (Device Info 0x80 + Transparent UART 0x40 = 0xC0)
            r = send_cmd(ser, b'SS,C0')

            if b'AOK' in r:
                print("  AOK! SS,C0 gesetzt.")
                # Neustart
                r_reboot = send_cmd(ser, b'R,1', wait=1.0)
                print(f"  R,1 -> {r_reboot!r}")
                return True
            else:
                print(f"  Kein AOK: {r!r}")
                send_cmd(ser, b'R,1', wait=1.0)  # trotzdem neu starten
        else:
            print("  Kein CMD>")

        time.sleep(2)

    return False


def check_no_crashloop(ser, observe_secs=6):
    """Beobachtet UART: gibt True zurück wenn kein Crash-Loop (kein %REBOOT%)."""
    print(f"\n[Check] Beobachte UART {observe_secs}s auf Crash-Loop...")
    buf = b''
    t0 = time.time()
    reboot_seen = False
    while time.time() - t0 < observe_secs:
        b = ser.read(1)
        if b:
            buf += b
            print(b.decode('ascii', 'replace'), end='', flush=True)
        if b'%REBOOT%' in buf:
            reboot_seen = True
            buf = b''
    print()
    return not reboot_seen


def main():
    print(f"Öffne {PORT} (dsrdtr=False, rtscts=False)...")
    with open_port() as ser:
        time.sleep(0.3)
        ser.reset_input_buffer()

        # Erst prüfen ob Crash-Loop aktiv ist
        in_stable_state = check_no_crashloop(ser, observe_secs=5)

        if not in_stable_state:
            print("Crash-Loop erkannt → Phase 1: SF,2 senden")
            ok = phase1_stop_crashloop(ser)
            if not ok:
                print("FEHLER: SF,2 konnte nicht gesendet werden.")
                return
        else:
            print("Kein Crash-Loop → direkt zu Phase 2")

        # Phase 2: SS,C0 setzen
        ok = phase2_set_services(ser)

        if ok:
            print("\n" + "="*50)
            print("ERFOLG! Transparent UART konfiguriert.")
            print("Jetzt: Modul vollständig vom Strom trennen (5s),")
            print("       dann einschalten → GATT-Tabelle wird neu gebaut.")
            print("Dann: python3 rn4871_ble_test.py <MAC>")
            print("="*50)
        else:
            print("\nFEHLER: SS,C0 konnte nicht gesetzt werden.")
            print("Mögliche Ursachen:")
            print("  1. Linux/Windows BT ist noch an (auto-connect blockiert $$$)")
            print("  2. P2_0 ist auf GND (Bootloader-Modus)")
            print("  3. Modul nicht erreichbar")


if __name__ == '__main__':
    main()

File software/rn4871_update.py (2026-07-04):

#!/usr/bin/env python3
"""
RN4871 Firmware Update over UART (HCI bootloader protocol)

Voraussetzung:
  - P2_0 auf GND + Reset: Modul im Bootloader-Modus
  - UART-Adapter an TX/RX des Moduls
  - pip install pyserial intelhex

Aufruf:
  python3 rn4871_update.py /dev/ttyUSB0 RN4870-71_Firmware_1.44/Hex_Files/RN487x_V1.44_Rehex_0EF2.HEX
"""

import serial
import struct
import sys
import time
from intelhex import IntelHex

# HCI Pakettypen
CMD_PKT   = 0x01
ACL_PKT   = 0x02
EVENT_PKT = 0x04

CHUNK_SIZE       = 128
FLASH_TOTAL_SIZE = 0x40000
TIMEOUT_S        = 10.0
ERASE_TIMEOUT_S  = 30.0


# ---------------------------------------------------------------------------
# Paket-Builder
# ---------------------------------------------------------------------------

def pkt_connect():
    """HCI Create Connection (opcode 0x0405) mit allen Nullen = Flash-Session."""
    params = bytes(13)  # addr(6) + type(2) + mode(1) + rsvd(1) + offset(2) + role(1)
    return struct.pack('<BHB', CMD_PKT, 0x0405, len(params)) + params


def pkt_disconnect(handle):
    """HCI Disconnect (opcode 0x0406)."""
    params = struct.pack('<HB', 0x0FFF, 0x00)
    return struct.pack('<BHB', CMD_PKT, 0x0406, len(params)) + params


def pkt_erase(handle):
    """ACL Data: Flash Erase (cmd_id 0x0112)."""
    # DATA_PKT body: cmd_id(2)+data_len(2)+mem_type(1)+mem_subtype(1)+addr(4)+size(4) = 14 bytes
    body = struct.pack('<HHBBII', 0x0112, 10, 0x03, 0x00, 0x00000000, 0x00000000)
    return struct.pack('<BHH', ACL_PKT, handle, len(body)) + body


def pkt_write_start(handle, data, total_size):
    """ACL Data: Write-Start mit write_continue-Flag (cmd_id 0x0111)."""
    acl_len = 14 + len(data)
    pgm_data_len = (acl_len - 4) | 0x8000  # bit 15 = write_continue
    body = struct.pack('<HHBBII', 0x0111, pgm_data_len, 0x03, 0x00, 0x00000000, total_size)
    body += data
    return struct.pack('<BHH', ACL_PKT, handle, acl_len) + body


def pkt_write_continue(handle, data, last=False):
    """ACL Data: Write-Continue (cmd_id 0x0001). last=True → kein write_continue-Flag."""
    acl_len = 4 + len(data)
    pgm_data_len = len(data) if last else (len(data) | 0x8000)
    body = struct.pack('<HH', 0x0001, pgm_data_len) + data
    return struct.pack('<BHH', ACL_PKT, handle, acl_len) + body


# ---------------------------------------------------------------------------
# UART-Empfang
# ---------------------------------------------------------------------------

def read_event(ser):
    """Liest ein HCI-Event-Paket (0x04). Gibt (event_code, data_bytes) zurück."""
    ptype = ser.read(1)
    if not ptype:
        raise TimeoutError("Timeout beim Lesen des Pakettyps")
    if ptype[0] != EVENT_PKT:
        raise ValueError(f"Unerwarteter Pakettyp: 0x{ptype[0]:02X} (erwartet EVENT 0x04)")
    event_code = ser.read(1)[0]
    length = ser.read(1)[0]
    data = ser.read(length)
    return event_code, data


def read_acl(ser):
    """Liest ein HCI-ACL-Datenpaket (0x02). Gibt (handle, data_bytes) zurück."""
    ptype = ser.read(1)
    if not ptype:
        raise TimeoutError("Timeout beim Lesen des ACL-Pakettyps")
    if ptype[0] != ACL_PKT:
        raise ValueError(f"Unerwarteter Pakettyp: 0x{ptype[0]:02X} (erwartet ACL 0x02)")
    handle = struct.unpack('<H', ser.read(2))[0]
    length = struct.unpack('<H', ser.read(2))[0]
    data = ser.read(length)
    return handle, data


def read_any(ser):
    """Liest das nächste HCI-Paket. Unbekannte Bytes werden übersprungen."""
    while True:
        ptype = ser.read(1)
        if not ptype:
            raise TimeoutError("Timeout")
        t = ptype[0]
        if t == EVENT_PKT:
            event_code = ser.read(1)[0]
            length = ser.read(1)[0]
            data = ser.read(length)
            return (EVENT_PKT, event_code, data)
        elif t == ACL_PKT:
            handle = struct.unpack('<H', ser.read(2))[0]
            length = struct.unpack('<H', ser.read(2))[0]
            data = ser.read(length)
            return (ACL_PKT, handle, data)
        else:
            print(f"  [sync] unbekanntes Byte 0x{t:02X}, übersprungen")


def wait_for(ser, pkt_type):
    """Wartet auf ein Paket eines bestimmten Typs, ignoriert andere."""
    while True:
        pkt = read_any(ser)
        if pkt[0] == pkt_type:
            return pkt


def check_acl_status(data):
    """Prüft bytes [4:6] im ACL-Response-Payload auf 0x0000."""
    if len(data) < 6:
        raise RuntimeError(f"ACL-Antwort zu kurz: {data.hex()}")
    status = struct.unpack('<H', data[4:6])[0]
    if status != 0x0000:
        raise RuntimeError(f"Fehler in ACL-Antwort: 0x{status:04X}")


# ---------------------------------------------------------------------------
# Hauptprogramm
# ---------------------------------------------------------------------------
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

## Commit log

2025-11-08 initial upload
    [Bottom_MicroUSB.stl, Bottom_MicroUSB.stp, Top_slope.stl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]
2025-11-08 Expand README with usage details and images
    Added detailed instructions and images for the 3D printable IR-UART TTL Adapter.
2025-11-08 Update README with Rhino version and printing details
    Added details about Rhino 8 and printing specifications.
2025-11-08 Specify PETG material for enclosure printing
    Updated material used for enclosure printing to PETG.
2025-11-10 Added USB-C bottom part
    [Bottom_USB-C.stl, Bottom_USB-C.stp]
2026-07-04 Add RN4871 BLE version section and polish existing README
    - Fix typos/grammar in the CP2102 section (enclosure, contour, 4.7k, capitalization)
    - Add separated "RN4871 Version (Bluetooth Low Energy)" section
    - Add 3x4 fixed-size image grid (1-12); 8/9/10 are .png, 11/12 pending
    - Document the optical front-end, 680 Ohm sweet spot and BLE->com0com data path
2026-07-04 Clarify RN4871 decoupling caps requirement in README
    The previous wording ("no capacitor needed") was misleading. Two bypass
    caps (100 nF + 4.7-10 uF) between VDD and GND are mandatory; without them
    the module browns out on start-up/pairing and cannot be programmed. Only
    the RX line needs no extra components.
2026-07-04 Fix RN4871 baud rate to 9600 and note reconfiguration
    The DE-5000 IR output is 9600 8N1, not 19200. The RN4871 UART defaults
    to 115200, so it must be reconfigured once (SB,09) to match the meter.
2026-07-04 List STP/STL/3DM enclosure files in README
2026-07-04 updated drawings
    [DE-5000_IR_RN4871.3dm, DE-5000_IR_RN4871_housing-cover.stl, DE-5000_IR_RN4871_housing-cover.stp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]
2026-07-04 Add Programming Adapter (pogo-pin fixture) section
    Standard perfboard could not contact the tiny, tightly spaced RN4871/
    RN4871U pads, so a dedicated pogo-pin fixture was designed. Adds section
    with images 13-22 and the RN4871/RN4871U fixture STP/STL/3DM files, plus
    RESET_N + P2_0 switches and the mandatory 100nF/10uF decoupling caps note.
    [RN4871U_fixture.3dm, RN4871U_fixture.stl, RN4871U_fixture.stp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]
2026-07-04 Add clamp/magnet lid details and two image placeholders
    RN4871 fixture holds the module with a plastic clamp; the RN4871U version
    uses a lid closed by two mini neodymium magnets. Extend the programming
    adapter grid with placeholders 23/24 to fill the last row.
2026-07-04 Add sanitized software/: BLE-to-COM bridge, tools and full write-up
    Adds the Python software under software/ (bridge + flashing/config/diag
    scripts, quick-reference) and a comprehensive "Software" section to the
    README: the debugging journey, the BLE Transparent UART UUIDs/subscription,
    a step-by-step Windows setup (com0com + bridge) and a per-tool reference.
    All identifying data removed: module MACs -> AA:BB:CC:DD:EE:FF, lab host ->
    192.0.2.10 (overridable via --mac / BB3_HOST), absolute paths made relative.
    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
2026-07-04 Scrub Windows username from Rhino .3dm files
    Rhino embeds render-content texture cache paths (C:\Users\sw\...) in the
    .3dm files. Byte-length-preserving replacement sw -> __ in all four .3dm;
    geometry verified intact (opens cleanly in Rhino). STL/STEP were already
    clean; no license/serial data is stored by Rhino.
    [DE-5000_IR_RN4871.3dm, DE-5000_IR_USB.3dm, RN4871U_fixture.3dm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]
